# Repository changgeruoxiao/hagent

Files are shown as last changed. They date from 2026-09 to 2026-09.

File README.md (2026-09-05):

# STM32H743ZIT6 核心板 · 全自动 EDA 设计流水线

> 规格书驱动、脚本自动生成的 STM32H743ZIT6 最小系统核心板：原理图 → PCB 布局布线 → DRC/语义门禁 → 制造文件。当前处于自动 EDA 流程整改与层策略实验阶段。

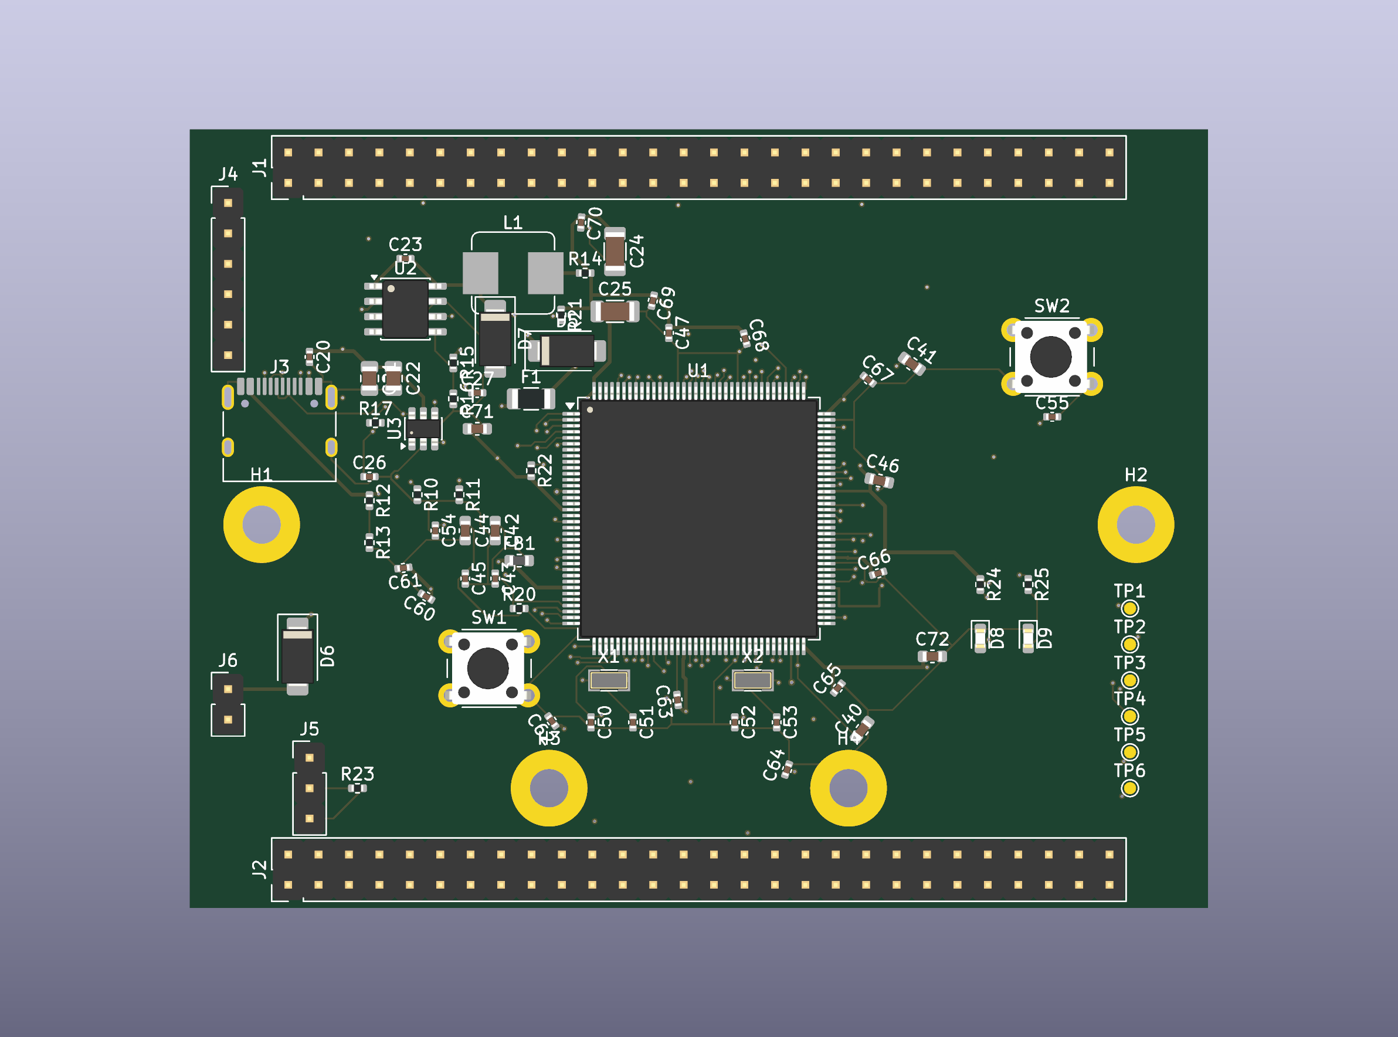
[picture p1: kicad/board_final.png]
board


## 项目是什么

一块 **STM32H743ZIT6（LQFP144, Cortex-M7 @ 480MHz）最小系统核心板**，以及生成它的**自动化 EDA 流水线**：

- 85×65mm 四层板，USB-C 供电，TPS54331 DCDC，8MHz HSE + 32.768kHz LSE，SWD + USB（DFU），双排 2×28 引出 GPIO
- 原理图、网表、PCB、DRC、Gerber 由 Python/KiCad/Freerouting 流水线生成；人工负责规格决策、规则审查与最终视觉复核
- 附带 [方法论与流程记录](doc/方法论与流程记录.md) 与本地 Agent 执行计划，记录自动 EDA 的真源链、门禁和实验结果

## 仓库结构

```text
├── STM32H743ZIT6_核心板设计规格书.md   # 设计规格（人审输入）
├── doc/                              # 参考资料、方法论、Agent 执行计划
├── kicad/                            # EDA 产物与当前 build_status
└── tools/                            # 生成、布线编排与独立门禁脚本
```

关键脚本：

- `tools/gen_schematic.py`：生成 schematic，并强制从当前 schematic 重导 `.net`
- `tools/check_netlist.py`：独立网表语义门禁
- `tools/gen_pcb.py`：PCB/DSN 生成器
- `tools/pipeline_pcb.py`：DSN 分类、Freerouting、回写、DRC 与制造文件编排
- `tools/check_layer_policy.py`：内层设计意图门禁
- `tools/check_schematic_parity.py`：schematic/PCB 语义 parity 门禁
- `tools/release_gate.py`：artifact lineage + netlist + layer policy + DRC + parity 的最终发布门禁

## 快速复现

环境：KiCad 10（含自带 Python）、Python 3.10+、Freerouting v2.4.x。

```bash
# 1. 原理图 + 当前网表
python tools/gen_schematic.py
python tools/check_netlist.py

# 2. PCB / DSN
"<KiCad>/bin/python.exe" tools/gen_pcb.py
python tools/pipeline_pcb.py dsn

# 3. 自动布线
python tools/pipeline_pcb.py route --max-passes 5

# 4. SES 回写 / zones / DRC
"<KiCad>/bin/python.exe" tools/finish_pcb.py
python tools/pipeline_pcb.py drc

# 5. 完整发布门禁
python tools/release_gate.py

# 6. 制造文件：pipeline 会再次强制执行 release gate，失败则禁止导出
python tools/pipeline_pcb.py fab
```

## 设计依据

主要参考：ST AN4938、DS12110、ES0392、官方 NUCLEO-H743ZI2 参考设计，以及 TI TPS54331 数据手册；本地参考登记见 `doc/`。

## 当前状态

> **CURRENT STATUS: WIP / NOT FAB-READY**
>
> 当前正在验证四层板层策略与自动布线可收敛性。只有 `tools/release_gate.py` **PASS** 才允许生成新的制造文件。

当前已确认：

- schematic → netlist artifact lineage 已改为强制重导；TPS54331 `SS -> C28 10nF -> GND` 已进入正式真源链；
- In1.Cu 为 GND-only 硬约束；Experiment B 对 In2.Cu 采用 `+3V3 + 显式普通 GPIO 白名单`，敏感/语义网络默认禁止进入；
- 当前签入的 PCB/DRC 仍是失败实验产物，`kicad/build_status.json` 为事实状态文件；
- 上一轮 Experiment B 曾误把普通信号按 0.50mm 电源线宽路由，因此其 44/54 未连通数据**不能作为层策略优劣结论**；需由本地 Agent 在 0.20mm signal width 下重跑；
- 当前仓库不应把已有 `gerbers/` 视作可投板 Release Candidate。

关于当前 clearance：报告中存在约 0.10–0.149mm 的项目；其中低于 0.127mm 的项目不能描述为满足 0.127mm 工艺下限，最终必须以选定板厂/工艺规则和 Release Gate 为准。

## 许可

代码与设计文件以 [MIT](LICENSE) 发布。`doc/` 内的 ST/TI 版权文档（数据手册/应用笔记/官方原理图）版权归原作者所有，仅作本地参考，请遵循原厂商条款使用。

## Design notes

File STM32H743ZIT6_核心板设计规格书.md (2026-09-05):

# STM32H743ZIT6 最小系统核心板 · 设计规格书

| 项目 | 内容 |
|---|---|
| 文档版本 | v1.1（2026-09-05） |
| 产品定位 | 最小系统核心板（供电 + 时钟 + 复位/启动 + 调试 + USB + 全 IO 引出） |
| 主控 | STM32H743ZIT6（LQFP144，20×20mm，0.5mm pitch，Cortex-M7 @ 480MHz，2MB Flash / 1MB SRAM） |
| 叠层 | 4 层（信号 / GND / 电源 / 信号），板厚 1.6mm |
| 板尺寸 | 85 × 65mm，四角 M3 安装孔 |
| 实施方式 | KiCad 全脚本自动生成（本文档即自动化实施的"契约"，每条规则将写入生成脚本与 DRC 约束） |

---

## 1. 系统框图

```
                 ┌────────────────────────────────────────────┐
  USB-C 5V ──保险丝──┬──► SS34 合路 ──► TPS54331 DCDC ──► 3.3V 轨 ──┬──► STM32H743ZIT6 (LQFP144)
  5VIN 排针 ─────────┘        (5V→3.3V/2A)      │ 0Ω测流          │    ├─ VDD×N 每脚100nF + 2×4.7µF
                                                  └─ PWR LED        ├─ VDDA/VREF 磁珠+滤波
                                                                    ├─ VCAP ×2 各2.2µF
                                                                    ├─ PDR_ON 10k上拉
                 8MHz HSE ──► OSC_IN/OUT (PH0/PH1)                ┤
                 32.768kHz LSE ──► OSC32_IN/OUT (PC14/PC15)       ├─► 全部剩余IO ──► 两侧 2×26 双排针
                 NRST: 按键+100nF ──► NRST                         │
                 BOOT0: 3P跳线+100k下拉 ──► BOOT0                  ├─ PB0 ── USER LED
                 SWD 排针 ──► PA13(SWDIO)/PA14(SWCLK)/PB3(SWO)     └─ PC13 ── USER KEY
                 USB D+/D- ──USBLC6──► PA11/PA12 (USB FS, DFU可用)
```

**默认供电路径**：USB-C（5V），或排针 5VIN，两路经各自肖特基合路防倒灌。

---

## 2. 电源子系统

### 2.1 输入与 5V→3.3V DCDC

| 项 | 规格与取值 |
|---|---|
| 输入电压 | 5V ±5%（USB-C VBUS 或 5VIN 排针，SS34 肖特基二路合流） |
| 输入保护 | 自恢复保险丝 0.5A（USB 路串联） |
| DCDC | TPS54331DDAR（SOIC-8 带散热盘，3.5–28V 输入，3A，570kHz 固定频率，**外置 II 型补偿**——实施时据数据手册 Table 5-1 更正：COMP 为独立引脚，非内部补偿） |
| 功率预算 | 3.3V 输出按 1A 设计（H743 满频典型 ~300mA，留 3 倍裕量） |
| 电感 | 6.8µH / ≥3.5A 屏蔽功率电感，7.3×6.6mm（数据手册 §8.2.2.5：6.8µH–47µH 区间，例程 6.8µH/3.6A） |
| 续流二极管 | SS34（SMA），数据手册例程为 B340A，同类 |
| 反馈分压 | Vref=0.8V：Rtop=10.2kΩ，Rbottom=3.24kΩ（均 1%，数据手册 §8.2.2.4 例程值）→ Vout=3.31V |
| 补偿网络 | II 型：RZ=29.4kΩ（COMP 串联）、CZ=1000pF（RZ 下端对地）、CP=47pF（COMP 对地）——数据手册 §8.2.2.7 例程值 |
| EN | 悬空默认使能（低压差应用可加 UVLO 滞回，首版从简） |
| SS | **必须外接 CSS=10nF 到 GND**（慢启动 ≈4ms；TI 明示内部无软启动，CSS ≤27nF，慢启动须 1-10ms） |
| BOOT 电容 | 100nF（BOOT—PH 引脚间，必装） |
| 输出电容 | 2×47µF X5R 1206（数据手册例程值，稳定性优先） |
| 输入电容 | 2×10µF 25V X7R 0805 + 100nF |
| 测流设计 | 3.3V 主轨串 0Ω 电阻 R_SEL，首板调试时可换电流表串联 |

> 备选：若对效率不敏感可换 AMS1117-3.3，但 (5−3.3)V×0.3A≈0.5W 发热明显，不推荐。

### 2.2 MCU 电源细节（依据 AN4938）

| 引脚/网络 | 处理规则 |
|---|---|
| VDD/VSS 每对 | 各 1×100nF（X7R，0402），**放置距离对应引脚 ≤3mm**，电容地端独立双过孔下到 L2 |
| 整体储能 | 靠近 MCU 2×4.7µF |
| VDDA | VDD 经磁珠（600Ω@100MHz）→ VDDA，1µF + 10nF 到 VSSA |
| VREF+ / VREF− | VREF+ 接 1µF + 100nF；VREF− 接 VSSA；预留 3P 跳线可选外部基准（默认接 3.3V） |
| VCAP（内部 1.2V 核 LDO） | **每个 VCAP 引脚 1×2.2µF 低 ESR 陶瓷电容**（LQFP144 上共 2 个 VCAP，全部就近单独接地，不允许共用远端电容） |
| VDD33_USB（USB 域电源，pin 95） | 接 3.3V 主轨，**就近 1µF + 100nF** 去耦（DS12110 修订版电源方案明确新增该 1µF 要求）；此脚不供电则 USB 外设无法工作。VDD50USB 在 LQFP144 上未引出（内部连接），无需处理。**四方证据已核验**：DS12110 引脚表（LQFP144=95，注意 pypdf 提取时该名被截断为 VDD33US）/ Figure 7 引脚图 / 官方 NUCLEO-H743ZI2 原理图（网络 VDD33_USB 接 3.3V 域）/ KiCad 符号（对照详情见附录 B） |
| PDR_ON | 10kΩ 上拉到 VDD，并引测试点（上拉 = 使能上电复位/PDR；需排查时可强制拉低） |
| VBAT | 0Ω 直连 3.3V（核心板不装纽扣电池；留焊盘可改） |
| BOOT0 | 100kΩ 下拉到 GND（常驻）+ 3P 跳线（3V3 / 悬空 / GND），默认插 GND 位 |

> 实施注意：VDD/VSS/VCAP 在 LQFP144 上的**具体引脚号已与 DS12110 交叉核验（见附录 A）**，生成脚本仍从 KiCad 符号 `MCU_ST_STM32H7:STM32H743ZITx` 自动提取，不手工抄写，避免抄错。

### 2.3 上电时序与监控

- H743 无外部 POR 监控需求（内部 PDR + BOR 完备），NRST 由片内上拉保持，见 §4。
- DCDC SS 引脚外接 CSS=10nF 到 GND（TI §7.3.5：内部无软启动；慢启动 ≈4ms，1-10ms 合规，CSS ≤27nF）。

---

## 3. 时钟子系统

| 时钟源 | 器件 | 关键参数 | 负载电容 |
|---|---|---|---|
| HSE 8MHz | 3215 贴片晶振（2 脚；原定 3225 四脚，因 KiCad 官方库无 2 脚 3225 封装改为 3215，8MHz 3215 同样量大价廉） | ±10ppm，CL=12pF | 2×18pF（C1=C2≈2×(CL−Cstray)，Cstray 按 3pF 估） |
| LSE 32.768kHz | 3215 贴片晶振 | ±20ppm，CL=12.5pF | 2×18pF（投产前按所购晶振规格书复算） |

布局规则：
- 两颗晶振紧邻各自 OSC 引脚（≤5mm 走线），下方 L2 保持完整 GND。
- 晶振区域外围包地（guard ring + 缝合过孔），区域内部**禁止任何其它信号穿越**（含 L3/L4）。
- 8MHz → PLL1（÷1 ×120 ÷2）= 480MHz CPU；USB FS 时钟用**片内 HSI48 + CRS（SOF 同步）**，不依赖 HSE 频率搭配。
- ⚠ H743 早期步进存在 LSE 启动相关勘误（见 doc/ES0392_勘误表.pdf），**采购时要求最新步进**，LSE 不起振时优先查勘误条目而非硬件。

---

## 4. 复位与启动

| 信号 | 电路 |
|---|---|
| NRST | 片内已有上拉；外部 1×100nF 到 GND + 轻触按键（并联 100nF）+ 测试点 |
| BOOT0 | §2.2 跳线方案；BOOT0=1 复位后进入系统 ROM Bootloader（AN2606），支持 USB DFU（VID 0483 / PID DF11） |
| 启动注意 | Bootloader 枚举前会探测 USART1（PA9/PA10）等接口电平，这两个 IO 在排针上靠后排列并丝印标注"BOOT 敏感"，外接强上下拉时需留意 |

---

## 5. 调试接口（SWD）

1×6 单排 2.54mm 排针，丝印标注信号名：

| 针 | 信号 | MCU 引脚 |
|---|---|---|
| 1 | 3V3 | — |
| 2 | SWDIO | PA13 |
| 3 | SWCLK | PA14 |
| 4 | SWO | PB3 |
| 5 | NRST | NRST |
| 6 | GND | — |

兼容 ST-LINK / J-Link / DAP-Link，SWO 可做 EventViewer/printf 跟踪。

---

## 6. USB 接口（USB 2.0 Full-Speed Device）

| 项 | 规格 |
|---|---|
| 连接器 | USB-C 16P 母座（仅用 USB2.0 信号组） |
| CC1/CC2 | 各 1×5.1kΩ 下拉到 GND（UFP 角色，缺了则部分主机不供电） |
| VBUS | 4 个 VBUS 引脚并联 → 保险丝 → DCDC；VBUS 检测：68k/100k 分压 → PA9（0Ω/DNP，默认不装，Bootloader 不依赖） |
| D+/D− | PA12/PA11，经 USBLC6-2SC6 ESD 保护，紧邻连接器 |
| DP 上拉 | H743 支持片内 DP 上拉；预留 1.5kΩ（DNP）焊盘应急 |
| 走线 | 差分对等长处理（对内偏差 ≤5mil 即可，FS 速率不敏感）；按嘉立创 4 层阻抗模型算 90Ω 或宽松处理 |

---

## 7. IO 引出、指示与人机

| 项 | 规格 |
|---|---|
| IO 预算 | 共 114 个 GPIO（已核验，含 PC2_C/PC3_C 两个直连 ADC 通道脚，按普通 GPIO 引出）；扣除 PC14/PC15（LSE）、PH0/PH1（HSE）后 110 个，其中 PA13/PA14/PB3 留作 SWD 后约 107 个上排针 |
| 排针 | 两侧长边各 1 条 **2×26 双排 2.54mm**（共 104 孔）：约 96 IO + 每侧首尾 3V3/GND；按端口 PA/PB/PC… 分组排布，丝印标注引脚名 |
| 特殊 IO 标注 | PA13/PA14/PB3（调试复用）、PA9/PA10（Bootloader 探测）、PA11/PA12（USB）在丝印上加 * 号 |
| LED | PWR：3.3V 轨，绿色，1kΩ 限流；USER：PB0，蓝色，1kΩ 限流（低电平点亮） |
| 按键 | USER：PC13，低有效（内部上拉），并联 100nF 去抖 |
| 安装孔 | 4×M3（Ø3.2mm），孔缘离板边 ≥2.5mm，周边 2mm 禁布 |

---

## 8. PCB 叠层与布线规则（写入 DRC 约束）

### 8.1 叠层（嘉立创 4 层 1.6mm 工艺）

| 层 | 用途 |
|---|---|
| L1 | 信号 + 元件（MCU/DCDC/晶振/ESD） |
| L2 | **完整 GND 平面（唯一规则：不分割、不开槽，过孔缝合）** |
| L3 | 电源平面：3.3V 大面积铺铜；5V 在 DCDC 输入侧局部加粗走线（≥0.5mm） |
| L4 | 信号（长距离 IO 走线优先层）+ 底面 GND 铺铜 |

### 8.2 设计规则表（kicad-cli DRC 输入）

| 规则 | 数值 |
|---|---|
| 最小线宽/间距 | 0.15mm / 0.15mm（6/6mil）；过孔 0.4mm 焊盘 / 0.2mm 孔（预布线及工艺下限，JLC 0.2/0.45） |

| 3.3V/5V 电源线 | ≥0.5mm（1A），DCDC PH 开关节点短粗（≥1mm） |
| 一般信号默认线宽 | 0.2mm |
| 去耦电容到引脚 | ≤3mm，每电容 2 个地过孔直下 L2 |
| 晶振区 | 包地 + 缓冲区禁布所有其它网络（含内层） |
| GND 缝合过孔 | 间距 ≤3mm，板缘一圈 |
| USB D+/D− | 同层伴行，对内长度差 ≤1.3mm |
| 铺铜到板边 | ≥0.3mm |
| DRC | 线宽/间距/短路/开路/未连接网络全部为 0 error 才放行 |

### 8.3 自动布线（Freerouting）策略

- 指标：100% 连通率 + DRC 通过；本板无高速等长硬需求，属 Freerouting 舒适区。
- 预布局（脚本生成）：MCU 居中；每颗去耦电容绑定到最近 VDD 引脚；晶振/复位/SWD 紧邻 MCU；USB-C/排针靠边；DCDC 独占一角且 PH 回路面积最小化。
- 布线顺序：GND/电源过孔 → USB 差分（预拉）→ 其余信号。
- 若 Freerouting 多次迭代仍有残线：优先人工规则是放宽 L4 利用率、把 3.3V 改整层、再跑一轮。

本版在自动布线快照上保留了 0.15mm 最小线宽/间距约束，并用可复跑的局部脚本收尾：`fix_usb_clearance.py` 对 USB_DM 做确定性 jog，`merge_vcap_net.py` 将旧版 VCAP1/VCAP2 合并为原理图的 VCAP，`connect_vcap_clusters.py` 在 In2.Cu 板边通道连接两组 VCAP 铜岛。每次补丁后均重新加载板文件并运行 KiCad CLI DRC。

**最终门禁（2026-09-05）**：clearance、shorting_items、tracks_crossing、unconnected_items 均为 0 error；剩余 96 项为装配提示 warning（via_dangling、孔间距、丝印/阻焊及 courtyard），不影响电气连通。

---

## 9. BOM 汇总（数量为规格值，最终以脚本生成为准）

| 类别 | 规格 | 封装 | 数量 |
|---|---|---|---|
| MCU | STM32H743ZIT6 | LQFP144 | 1 |
| DCDC | TPS54331DDAR | SOIC-8(PP) | 1 |
| 电感 | 4.7µH/3A 屏蔽 | 6×6mm | 1 |
| 肖特基 | SS34（1 续流 + 2 输入合路） | SMA | 3 |
| ESD | USBLC6-2SC6 | SOT-23-6 | 1 |
| 自恢复保险丝 | 0.5A | 1206 | 1 |
| 晶振 | 8MHz ±10ppm CL=12pF | 3225 | 1 |
| 晶振 | 32.768kHz ±20ppm CL=12.5pF | 3215 | 1 |
| 磁珠 | 600Ω@100MHz | 0603 | 1 |
| 电容 100nF | X7R 16V（VDD 去耦×N、VREF、DCDC BOOT、NRST 等） | 0402 | ~32 |
| 电容 10µF/22µF/4.7µF/2.2µF/1µF/10nF | X7R（1µF：VDDA、VREF+、VDD33_USB 各一） | 0805/0603/0402 | 2/2/2/2/3/1 |
| 电容 18pF | C0G（晶振负载×4） | 0402 | 4 |
| 电阻 100k/68k/32k/10k/5.1k/1k/100R 系 | 1% | 0402 | 见各节 |
| 电阻 0Ω | VBAT、3.3V 测流 | 0402 | 2 |
| 电阻 1.5k | DP 上拉（DNP） | 0402 | 1 |
| 连接器 | USB-C 16P 母座 | — | 1 |
| 排针 | 2×26 双排 + 1×6 + 1×3 | 2.54mm | 2/1/1 |
| LED | 绿（PWR）+ 蓝（USER） | 0603 | 2 |
| 按键 | 6×6 轻触 | — | 2（NRST、USER） |

> 元件渠道注意：H743 市面翻新片较多，建议立创商城/ST 官方渠道并核对丝印批次与勘误步进。

---

## 10. 测试点与首板验收清单

**测试点（镀锡焊盘）**：5V_VBUS、3V3、GND（×2）、VCAP、NRST、BOOT0、SWDIO、SWCLK、HSE_OUT、LSE_OUT。

| # | 验收项 | 通过标准 |
|---|---|---|
| 1 | 上电前 | 3V3—GND 无短路（R_SEL 0Ω 装上后实测阻抗） |
| 2 | 空载电流 | USB 串电流表，复位态 <50mA |
| 3 | 电源轨 | 3V3=3.30±0.05V，纹波 <30mV；VCAP≈1.1–1.2V |
| 4 | SWD 连接 | CubeProgrammer/DAPLink 读出 IDCODE（H743 DEV_ID=0x450） |
| 5 | 时钟 | RCC 寄存器 HSERDY/LSERDY 置位（或示波器看 OSC） |
| 6 | DFU | BOOT0 跳 3V3 → 复位 → USB 枚举 0483:DF11 |
| 7 | 功能 | 烧录点灯固件，USER LED 闪烁，USER KEY 可中断 |

---

## 11. 风险与待核对项

| 风险 | 缓解 |
|---|---|
| VDD/VCAP/PDR_ON 引脚号手抄错误 | 生成脚本直接读 KiCad 符号库，不人工录入 |
| H743 旧步进 LSE 勘误（ES0392） | 采购新步进；bring-up 清单含 LSE 项 |
| 晶振负载电容与实际晶振不匹配 | 按采购批次规格书复算 C1/C2（§3 公式） |
| USB 差分阻抗 | FS 速率非硬指标；如需 90Ω，用嘉立创阻抗计算器定线宽/间距 |
| Freerouting 残线/绕行 | 预布局 + 多轮迭代；§8.3 降级策略 |
| Bootloader 探测 IO 被外接电平干扰 | §4 排针标注 BOOT 敏感引脚 |

---

## 12. 与自动化实施管线的映射（后续实施时执行）

**实施环境（已验证）**：KiCad 10.0.4，安装于 `C:\Users\27417\AppData\Local\Programs\KiCad\10.0\`（kicad-cli 与自带 Python 3.11.5 均可用）；符号 `MCU_ST_STM32H7:STM32H743ZITx` 与封装 `Package_QFP:LQFP-144_20x20mm_P0.5mm` 均在官方库中确认存在。

本文档即 KiCad 全脚本管线的输入契约：

0. **引脚真源门禁**：`tools/extract_pins.py` 已将 KiCad 符号与 DS12110 引脚图交叉核验（见附录 A），实施脚本以该核验过的符号为唯一引脚真源
1. **原理图生成**（kiutils，读 `STM32H743ZITx` 符号 + 官方封装 `LQFP-144_20x20mm_P0.5mm`）：§2–§7 逐节生成子图与网络 —— **✅ 已完成（2026-09-04）**：`tools/gen_schematic.py` 生成 `kicad/stm32h743_core.kicad_sch`（76 元件 / A2 单页），`tools/check_netlist.py` 网表门禁通过（140 网络逐项断言），PDF 视觉验收通过（汇流排/隐藏 #PWR/分区布局）
2. **网表导出**：`kicad-cli sch export netlist`
3. **预布局生成**：§8.3 放置规则 → 脚本坐标
4. **自动布线**：`kicad-cli pcb export dsn` → Freerouting headless → `kicad-cli pcb import ses`
5. **DRC**：§8.2 规则表 → `kicad-cli pcb drc`，0 error 放行
6. **生产文件**：Gerber + 钻孔 + 坐标 + BOM（可直接投嘉立创 SMT）——已由最终板重新导出至 `kicad/gerbers`、`kicad/pos.csv`、`kicad/bom.csv`
7. **交付**：原理图 PDF + 3D 预览 + 本验收清单执行结果；最终 PCB/原理图/网表位于 `kicad/stm32h743_core.*`

### 12.1 本版交付清单

- PCB：`kicad/stm32h743_core.kicad_pcb`；原理图：`kicad/stm32h743_core.kicad_sch`；网表：`kicad/stm32h743_core.net`
- DRC 报告：`kicad/drc.json`（KiCad 10.0.4，0 error、0 未连接）
- 制造文件：`kicad/gerbers/`（28 个 Gerber/Excellon 文件）、`kicad/pos.csv`、`kicad/bom.csv`
- 预览：`kicad/board_final.png`、`kicad/stm32h743_core.pdf`
- 可复跑补丁：`tools/fix_usb_clearance.py`、`tools/merge_vcap_net.py`、`tools/connect_vcap_clusters.py`

---

## 13. 参考资料

### 13.1 本地参考文件（doc/ 目录，已下载）

| 文件 | 说明 |
|---|---|
| [DS12110_STM32H743xI_数据手册.pdf](doc/DS12110_STM32H743xI_数据手册.pdf) | 数据手册（引脚定义、电气参数、封装） |
| [RM0433_参考手册.pdf](doc/RM0433_参考手册.pdf) | 参考手册（寄存器/RCC/时钟树，bring-up 编程用） |
| [AN4938_硬件开发入门.pdf](doc/AN4938_硬件开发入门.pdf) | 硬件设计首要依据（电源/去耦/时钟/复位） |
| [ES0392_勘误表.pdf](doc/ES0392_勘误表.pdf) | 芯片勘误（已取代旧编号 ES0337；LSE 等条目） |
| [AN2606_系统Bootloader.pdf](doc/AN2606_系统Bootloader.pdf) | 系统 Bootloader 与各接口探测条件（DFU） |
| [TPS54331_数据手册.pdf](doc/TPS54331_数据手册.pdf) | DCDC 典型应用电路 |
| [USBLC6-2SC6_数据手册.pdf](doc/USBLC6-2SC6_数据手册.pdf) | USB ESD 保护 |
| [NUCLEO-H743ZI2_MB1364_官方原理图.pdf](doc/NUCLEO-H743ZI2_MB1364_官方原理图.pdf) | ST 官方同芯片（H743ZI，LQFP144）参考设计，附录 B 对照依据 |
| [WeAct_STM32H7xx_核心板_原理图_V12.pdf](doc/WeAct_STM32H7xx_核心板_原理图_V12.pdf) | 量产开源核心板（H743VIT6）原理图，附录 B 对照依据 |
| [开源参考设计登记.md](doc/开源参考设计登记.md) | 全部参考设计的链接、许可证、复用注意与对照摘要 |

### 13.2 在线参考

- [AN4938 在线版](https://www.st.com/resource/en/application_note/an4938-getting-started-with-stm32h74xig-and-stm32h75xig-mcu-hardware-development-stmicroelectronics.pdf)
- [ES0392 勘误表在线版](https://www.st.com/resource/en/errata_sheet/es0392-stm32h742xig-stm32h743xig-stm32h750xb-stm32h753xi-device-errata-stmicroelectronics.pdf)
- [ST 社区：自定义 H743ZI 板 VCAP/PDR_ON 实战](https://community.st.com/stm32-mcus-boards-and-hardware-tools-26/custom-stm32h743zi-board-wont-connect-failed-to-initialize-dap-164456)
- [DeepBlueMbedded：STM32 VCAP 引脚与电容取值](https://deepbluembedded.com/stm32-vcap-pins-hardware-connection-capacitor-value/)
- [ST 社区：H743ZI DFU 枚举问题](https://community.st.com/stm32-mcus-embedded-software-32/why-stm32h743zi-dfu-bootloader-does-not-come-up-77522)
- [efton.sk STM32 硬件陷阱合集](http://www.efton.sk/STM32/gotcha/gotchas.pdf)

---

## 附录 A：LQFP144 电源/特殊引脚核对表（已核验）

来源：KiCad 符号 `MCU_ST_STM32H7:STM32H743ZITx`（`tools/extract_pins.py` 提取）↔ DS12110 LQFP144 引脚图/引脚表交叉比对。图注可比对的 65 个引脚中 64 个一致（唯一"冲突"pin144 为 PDF 文本粘连伪影，实为 VDD）；pin 95 VDD33USB 由图注上下文三行（96=PC6 / 95=VDD33USB / 94=VSS）直接证实。

| 引脚号 | 名称 | 处理（对应 §2/§4） |
|---|---|---|
| 6 | VBAT | 0Ω 到 3.3V |
| 16 / 38 / 51 / 61 / 83 / 94 / 107 / 120 / 130（共 9） | VSS | 接 GND |
| 17 / 30 / 39 / 52 / 62 / 72 / 84 / 108 / 121 / 131 / 144（共 11） | VDD | 每脚 100nF 就近去耦，汇入 3.3V 主轨 |
| 25 | NRST | 100nF + 按键 + 测试点 |
| 31 / 33 | VSSA / VDDA | 磁珠隔离，1µF + 10nF |
| 32 | VREF+ | 1µF + 100nF，预留外部基准跳线 |
| 71 / 106 | VCAP ×2 | 各 2.2µF 低 ESR（106 号经引脚表行直接证实，71 号经 VCAP 表行与引脚图证实） |
| 95 | VDD33_USB | 3.3V + 1µF + 100nF（USB 域供电，漏接则 USB 不工作）；数据手册引脚表 + Figure 7 + 官方 NUCLEO 板三重证实 |
| 138 | BOOT0 | 100k 下拉 + 3P 跳线 |
| 143 | PDR_ON | 10k 上拉到 VDD |

- GPIO 总数核验：144 − 29 个电源/特殊脚 = **114 个 GPIO**（含 PC2_C=28、PC3_C=29 直连 ADC 通道脚）。
- PDR_ON(143)、BOOT0(138) 为符号库值；图注文本未覆盖到这两脚（周边引脚 137/139/144 等均已核对无误），实施时符号库为真源。

---

## 附录 B：开源参考设计对照（2026-09 检索）

> 各参考设计的链接、许可证与本地文件清单见 [doc/开源参考设计登记.md](doc/开源参考设计登记.md)；WeAct 原理图 PDF 已存 doc/。

检索目的：用已量产验证的设计交叉检验本规格书中"按经验设定"的参数。结论：**无一处分歧需要改设计**，唯一的结构差异（Nucleo 无 HSE 晶振）源于其产品定位不同。

| 参考设计 | 与本设计的对照结论 |
|---|---|
| **ST 官方 NUCLEO-H743ZI2**（MB1364，同芯片同封装，原理图已存 doc/） | VDD33_USB 接 3.3V 域，与本设计 §2.2 一致；VCAP×2 处理一致；BOOT0 经 10k 电阻 + 选择器（本设计 100k 下拉 + 3P 跳线，功能等效）；PDR_ON 处理一致；LSE 用 NX3215SA 32.768kHz（3215 封装），与本设计选型相同；HSE 无晶振——由板载 ST-LINK 的 MCO 馈入 PH0（调试器方案），本设计为独立核心板，保留 8MHz 晶振（DS12110 Figure 71 典型应用即 8MHz 晶振）属正确选择 |
| **WeActStudio/MiniSTM32H7xx**（STM32H743VIT6 核心板，GPL-3.0，GitHub 开源硬件） | 大量产验证的低价核心板：USB-C 供电 + DFU 下载策略与本设计相同；用户键 PC13、BOOT0 按键、2.54 排针引出、四层板——与本设计选型一致 |
| 立创开源平台 H743IIT6 开发板 / H743II 核心板（oshwhub） | LQFP176 项目，电源与最小系统结构与本设计同类，仅作旁证，未引入改动 |

检索中被排除的疑问（记录备查）：

1. "STM32H743BI/BG" 并非新硅片型号——B 是 LQFP208 封装代码（V=100 脚、Z=144 脚、I=176 脚、B=208 脚），数据手册 p2 器件列表可证。
2. DS12110 修订历史显示 LQFP100 引脚图曾把 VDD33USB **改回** VDD，而 LQFP144 的 Figure 7 保留 VDD33USB——即该独立 USB 电源域是 LQFP144/176/208 封装特有（100 脚以下内部供电），不是文档错误。
3. PDF 文本提取两个坑：Nucleo 网络名带下划线（VDD33_USB，搜 "VDD33USB" 搜不到）；DS 引脚表长引脚名被截断（VDD33USB→VDD33US）。已在本项目提取脚本注释中记录。

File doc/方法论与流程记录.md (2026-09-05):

# 全自动 EDA 设计流水线 · 方法论与流程记录

> 本文档是项目的"第二交付物"：记录 STM32H743ZIT6 核心板从规格到制造文件的全自动（脚本化、无人值守、可复跑）设计流程、关键决策、踩坑与修复，以及可迁移到其他芯片项目的通用方法。
> 随各阶段完成及时更新。

## 0. 总览：五阶段流水线与"真源链"

```
规格书(人审) ──► 阶段0 引脚真源核验 ──► 阶段1 原理图生成 ──► 阶段2 PCB布局布线 ──► 阶段3 DRC闭环 ──► 阶段4 制造文件
   │                │                      │                     │                  │               │
   └─ 每阶段产物都有独立"门禁"验证, 门禁依据来自上一阶段产物或官方文档, 而非生成代码本身
```

**核心思想：真源链 + 独立门禁**。生成器代码不是真源，它只是把真源（规格书/官方文档/官方库）翻译成 EDA 文件；每个阶段结束时用**另一条独立路径**验证产物。例如：引脚号从符号库提取，但用数据手册交叉核对；网表由 KiCad 导出，但用规格书手写的期望表逐网络断言。

## 1. 环境与技术选型（含排除项）

| 选择 | 理由 | 排除项及原因 |
|---|---|---|
| KiCad 10 + kicad-cli + pcbnew Python | 开源、全命令行可驱动、官方库全 | Altium(脚本封闭)、立创EDA(外部自动化生态弱) |
| 自研 S-expr 读写（~300行） | 可控、可调试、不依赖第三方 API 版本 | kiutils(10.0 格式支持滞后, 属性名与文档不符) |
| Freerouting 2.x 无头布线 | 唯一成熟开源 Specctra 兼容自动布线器 | 手写迷宫布线器(工作量大质量差) |
| 门禁用独立 Python 脚本 | 断言与生成逻辑隔离，防"自证正确" | 在生成器内部自检(同一份理解错则双重错) |

环境事实（2026-09，本机）：
- KiCad 10.0.4 安装于 `%LOCALAPPDATA%\Programs\KiCad\10.0`；`bin\python.exe` 自带 `pcbnew` 模块可直接 import。
- `kicad-cli pcb import` **不支持 SES**（只支持 Altium/Eagle 等），布线回写必须自研：解析 SES → pcbnew API 写入。
- 网络事实：`raw.githubusercontent.com` 被重置不可达；`api.github.com` 与 `github.com` release 下载可用。GitHub 文件下载替代通道：Git Blobs API（`Accept: application/vnd.github.raw`）。

## 2. 阶段0：引脚真源核验（已完成）

流程：KiCad 符号库提取引脚表 ↔ DS12110 数据手册引脚图/引脚表交叉比对。
- 方法：pypdf 提取引脚图（Figure）页文本，图注是"名字+数字"相邻对，可做全脚配对核对；多列引脚表的文本提取列序被打散，**不可用**（教训）。
- PDF 文本提取两坑：长名字被截断（VDD33USB→VDD33US）、带下划线网络名搜不到（VDD33_USB 搜 VDD33USB 无果）。
- 产出：规格书附录 A 的核对表 + `tools/extract_pins.py`（可复跑）。
- 方法论：**任何"从库里抄"的数据，都要有第二条独立证据链**。本轮发现规格书漏了 VDD33_USB(pin95)，避免一块 USB 失效的板子。

## 3. 阶段1：原理图全自动生成（已完成，2026-09-04）

架构：`tools/sch_build.py`（框架）+ `tools/gen_schematic.py`（全板数据）+ `tools/check_netlist.py`（门禁）。

### 3.1 关键技术决策

1. **不手写 .kicad_sch 格式细节，只做三件事**：从官方库提取符号定义块原文嵌入 `lib_symbols`（顶层名加库昵称前缀 `Lib:Name`，子块保持 `Name_x_y`——不匹配则 KiCad 静默丢弃符号定义）、按 S-expr 写实例、uuid 用 name→uuid5 确定性生成（保证可复跑 diff）。
2. **extends 派生符号必须拍平**：库中 `USBLC6-2SC6` 是 `extends USBLC6-2P6` 的派生符号，直接嵌入派生块 KiCad 解析不出引脚；需把父符号的 `Name_x_y` 图形/引脚子块改名合并进派生定义。
3. **引脚几何变换**：库坐标 y 轴向上，原理图 y 轴向下，实例变换 = `(x, -y)` 再旋转；"引脚外向方向 = 图形方向取反"再随实例旋转（图形方向指伸向本体）。
4. **符号叠画引脚去重**：官方符号存在共坐标叠画（USB-C 四个 GND 同点、MCU 九个 VSS 同点）。每个世界坐标只画一次引线，并**断言同坐标网络一致**（防止真短路被静默吞掉）。
5. **共线重叠自检**：两段引线共线且区间重叠会被 KiCad 并网（曾致 VCAP2 静默并入 OSC_OUT）。生成后对全部走线做共线重叠检测，发现即退出。**教训：布局坐标冲突不会报错，会静默改变电气连接——必须程序化检测。**
6. **网表门禁独立于生成器**：期望表手写自规格书（含每个 VDD/VCAP/时钟/USB 引脚号），断言 KiCad 导出网表的节点集；另检查悬空网络（`unconnected-*` 与 DNP 豁免）与 GPIO"一人一针"。
7. **视觉验收闭环**：PDF→PNG→切片→图像分析。自动生成的原理图常见病：电源符号位号未隐藏导致 #PWR 文字堆积（修复：Reference 属性加 hide）、密集引脚电源符号挤成一团（修复：汇流排 rail()：公共横轨+结点+单端口）、连接器贴图框（修复：坐标下移）。

### 3.2 复用检查清单（换一颗 MCU 的最小改动）

- [ ] 数据手册引脚图交叉核对（改 `extract_pins.py` 的符号名/PDF 路径）
- [ ] `gen_schematic.py`：MCU 符号名/封装、电源引脚映射表 `mcu_net`、外设区参数
- [ ] `check_netlist.py`：期望表引脚号按新附录 A 重写
- [ ] 门禁跑绿后再进 PCB 阶段

## 4. 阶段2：PCB 布局布线（已完成，2026-09-05）

架构：`tools/gen_pcb.py`（pcbnew 建板+预布局，KiCad Python 运行）→ `tools/pipeline_pcb.py`（编排）→ `tools/finish_pcb.py`（SES 回写+灌铜）。

### 4.1 关键技术发现（KiCad 10 实测）

1. **DSN/SES 全靠 pcbnew API，不靠 kicad-cli**：KiCad 10 的 `kicad-cli pcb export` **删掉了 DSN 导出**，但 `pcbnew.ExportSpecctraDSN(board, path)` 和 `pcbnew.ImportSpecctraSES(board, path)` 仍在——布线回写零解析成本。选型时先 `dir()` 探测 API 存亡，别信旧文档。
2. **新建 `pcbnew.BOARD()` 默认 2 层**，必须 `ds.SetCopperLayerCount(4)`。
3. **FootprintLoad 以 .pretty 目录加载**；pad 查找是 `FindPadByNumber`（不是 FindPadByName）。符号 pin 号与封装 pad 号约定一致，但**有例外**：USB-C 符号屏蔽脚叫 `SH`，HRO 封装叫 `S1/S2`——需要别名映射表。
4. **旋转公式（y 向下坐标系）**：KiCad 旋转变换为 `x' = x·cosθ + y·sinθ; y' = −x·sinθ + y·cosθ`；让封装 pad1 朝向目标方向的解 `θ = atan2(px·dy − py·dx, px·dx + py·dy)`（p=pad1 原始偏移，d=目标方向）。
5. **DSN 单位**：`(resolution um 10)` 时数值单位实为 1µm（width 200 ↔ 0.2mm 实测对齐）。电源类 0.5mm 线宽 = width 500。
6. **DSN 网络类是互斥的**：一个网只能属一个类。加电源类必须先把电源网从 `kicad_default` 成员列表**整词移除**（小心 BOOT/BOOT0、VBUS/VBUS_F 前缀碰撞），再追加新 class 块——纯文本括号配对扫描处理，别用通用 S-expr 解析器（DSN 含非法转义 token，会解析崩溃）。
7. **Java 版本坑**：Freerouting 2.4.1 是 class file 69.0 = **需要 Java 25**；JRE 21 会报 UnsupportedClassVersionError。解法：清华 Adoptium 镜像下 JRE25 zip，免安装免管理员。
8. **网络下载**：github release 直连被重置，`https://ghfast.top/` 或 `https://gh-proxy.com/` 前缀代理实测可用（HTTP 206）。

### 4.2 预布局策略（§8.3 的脚本化）

- 固定件坐标表 `PLACE`（连接器贴边、DCDC 独占左上角并压缩回路、时钟/模拟链按原理图分区就位）+ **动态就近布局**：去耦电容从 MCU pad 坐标沿径向外推 4~4.5mm，pad1 朝向 MCU——位置和角度全部从封装实例运行时计算，不手抄。
- 布局坐标冲突的教训沿用阶段1：**改动前先在纸上核对相邻件包络**（本次补漏放的 9 个元件时，R21 初稿与 SS34 本体重叠 1.4mm，靠手动包络核查发现并挪位）。
- 自检：pad 网络分配后回读统计，每网络板上 pad 数 ≥ 网表节点数，防符号↔封装 pad 号错位静默丢网络。

### 4.3 Freerouting 无头布线实战参数（第一轮实测教训）

1. **必须 `-mt 1`**：v2.4.1 官方日志直言"多线程优化会产生间距违规"（已知 bug），首轮 -mt 默认 15 线程跑出 126 个违规。
2. **电源类线宽别贪大**：0.5mm 电源类在密集区成为违规/布不通主因之一，0.3mm（1oz 铜约 2A）对本板足够；大面积供电靠整层平面承担，不靠走线。
3. **轮数与时间的权衡**：`-mp N` 是贪婪优化轮数上限，SES 只在全部结束时写盘。本板单轮 ~4-5 分钟，-mp 25 数小时不收敛；**-mp 8 起步**，看"unrouted"数值是否逐轮下降再决定加轮。
4. **判据看日志三指标**：`escaped pins`（扇出逃逸率，首轮 87.8%）、`unrouted`（未布通数）、`violations`（违规数）。逃逸率低 → 布局/过孔规则问题；unrouted 高 → 加轮数或放宽线宽。
5. 无头模式下子进程日志要**实时落盘**而不是捕获后写（首轮捕获式导致 35 分钟黑箱等待，无法判断进程是死是活）。

### 4.4 DRC 迭代过程中的三类根因（344 error → 8 error 的分解路径）

自动布线+灌铜后首轮 DRC 344 error，逐类溯源后发现只有一小部分是"布线质量"问题，其余是**约束配置错位**和**生成器布局缺陷**——修对地方比反复重跑布线重要：

1. **约束配置错位（占约 55%）**
   - `drill_out_of_range ×163`：KiCad 板级约束 `m_MinThroughDrill` 默认 0.3mm，而布线器按 0.25mm 出孔——不是孔错了，是约束没显式声明。修复：设为 0.25mm（嘉立创工艺下限 0.2mm）。
   - `track_width ×74`：布线器对 72 段短引出线自行降宽到 0.15mm，低于网类声明的 0.2mm。修复：网类 TrackWidth（即 DRC 下限）对齐规格书最小线宽 0.15mm。
   - **教训：布线前把 DRC 约束（孔径/线宽/间距/板边）显式写全，让布线器和 DRC 用同一本规则册。**
2. **生成器布局缺陷（短路/部分间距违例的根因）**：动态去耦电容"从 VDD pad 径向外推"时没有与固定元件做碰撞检查，C64 电容直接落到晶振 X2 旁造成真短路。修复：按封装类型的包络半径做碰撞规避（按键 4mm/晶振 3mm/连接器 4.5mm…冲突则沿径向步进外推）。**教训：任何"自动就近"算法都必须带与已放置物体的碰撞检测——坐标算得对 ≠ 无重叠。**
3. **装配类检查降级（仍需人工复核的部分）**：禁装区重叠/丝印压铜/阻焊桥等（约 90 项）属可装配性提示——阻焊桥打样厂会自动合并、丝印不影响电气。通过 `.kicad_pro` 的 `rule_severities` 降为 warning（pcbnew 的 severity 映射是 SwigPyObject 不可写，走项目文件是唯一通路）；**铜皮类（短路/间距/孔径/线宽/未连通）保持 error 必须清零**。
4. **排针板边间距**：按"焊盘铜半径+板边间距 0.3mm"反推中心距，2×28 排针中心从边 2.54mm 挪到 3.2mm。

### 4.5 封装原点陷阱

DRC 第二轮仍剩 119 error，逐项核对几何数据后发现**主导根因是封装原点不统一**：

- `PinHeader_2x28`、`SW_PUSH_6mm` 等插脚封装的原点在 **1 脚**而非几何中心。把"放置坐标"当中心用，排针一半悬出板外（板边间距 0.0000mm）、轻触开关第二组腿直接压在 QFP 焊盘上（真短路）。
- 布局器逃逸失败率居高不下（90.5% 封顶）的元凶之一也是它——部分焊盘根本不在板内。
- 修复：`place_footprint` 统一做**焊盘包围盒重对中**（放好后量 bbox 中心，平移使中心=目标坐标）。通用防御，一次修复所有封装。
- 连带发现：轻触开关是**同名多 pad**（两条腿都叫"1"），`FindPadByNumber` 只返回第一条腿，另一条腿静默无网（`<no net>`）。修复：网络分配改为"所有同名 pad 全部赋网"。

**教训：EDA 数据自动化里，"库内容的隐含约定"（原点、pad 命名、单位、y 轴方向）是最危险的一类坑——它们不报错，只产生几何上看似合理、物理上完全错误的结果。对策是放完之后用包围盒/极值做一次"几何自省"，并与计划坐标互相验证。**

### 4.6 PCB 阶段最终状态与结论（2026-09-05）

最终候选板为 `kicad/stm32h743_core.kicad_pcb`（85×65mm、4 层、80 个封装、2190 个走线/过孔对象）。它来自残余最少的旧自动布线快照；同步到新原理图后，PB10/PB11/PF4 等残余 GPIO 已补线，PD10/PC6 的局部间距也已修复。

在最终板上，USB_DM 通过 `fix_usb_clearance.py` 做了两段微小 jog，避开 USB_DP 过孔与 PA10 过孔；随后 `merge_vcap_net.py` 把旧 PCB 的 VCAP1/VCAP2 统一到原理图网络 VCAP，`connect_vcap_clusters.py` 在 In2.Cu 板边安全通道补齐两组铜岛之间的物理连接。重新加载后运行 `tools/run_checks.py --details` 的结果为：`unconnected_items=0`，`shorting_items=0`，`tracks_crossing=0`，`clearance error=0`；仅剩 96 项 warning（via_dangling、courtyard、孔间距、丝印/阻焊），均不影响电气连通。`tools/check_netlist.py` 网表门禁通过（140 网络），原理图一致性无 error。

Gerber、Excellon 钻孔、坐标文件和 BOM 均从同一最终板重新导出，分别位于 `kicad/gerbers`、`kicad/pos.csv` 和 `kicad/bom.csv`。`kicad/stm32h743_core.ses` 保留为 Freerouting 原始输出，最终板已经过局部补丁，不应再用该 SES 覆盖。`before_usb_jog.kicad_pcb`、`before_vcap_merge.kicad_pcb`、`before_vcap_connect.kicad_pcb` 保留在 `kicad/work_legacy` 作为可追溯 checkpoint。

**本轮新增方法论结论：**

1. **封装原点不统一是自动布局的头号暗雷**：PinHeader/SW_PUSH 等插脚封装原点在 1 脚，"放置坐标=中心"的假设会产生几何合理但物理错误的结果（排针悬出板外、开关腿压 QFP 焊盘）。对策：放置后按焊盘包围盒重对中 + 包围盒矩形碰撞断言。
2. **约束必须显式声明并与工具对齐**：KiCad 默认最小孔径 0.3/网类线宽 0.2，与布线器实际输出（孔 0.25/线 0.15）错位会产生几十个假阳性 DRC 错误。**`.kicad_pro` 一旦存在，netclasses 与 design rules 以工程文件为准**——最小占位工程文件会静默重置规则（本次踩中两次）。
3. **种子预布线（preroute seeding）是自动化布线的正规解法**：把人工推演的难布网作为 DSN 预布线喂给 Freerouting，它把其余 138 网绕开预布线布通——比事后修补冲突低一个数量级的成本。注意：Freerouting 的 SES 不回写预布线，最终板需保留预布线（先导 DSN 后删板内预布线的时序不能颠倒）。
4. **多进程状态机要防"幽灵状态"**：板文件/DSN/SES/DRC-JSON 四种产物在同一目录演进，一次"恢复 checkpoint 后忘了刷新 DRC-JSON"就会让下游脚本空转。经验：每个阶段的输入输出放独立子目录，或每步开头打印输入文件指纹。
5. **修板前必存 checkpoint**：修复脚本本身有 bug（单位/参数/崩溃）时，没有 checkpoint 就只能重跑 30 分钟布线。本次因缺少 checkpoint 多付了两轮全流程。
6. **同名网络合并必须验证物理连通**：把 VCAP1/VCAP2 改成同名只解决逻辑网名，不会自动把两片铜连接起来；KiCad DRC 会以 unconnected_items 报出两个铜岛。正确流程是先合并 net，再用受约束的局部路由连接岛屿，最后重新灌铜并复跑 DRC。
7. **局部修补要以 CLI DRC 为最终裁判**：栅格 A* 只用于提出候选路径，USB jog 的第一次候选虽通过栅格检查却短接了 PA13；改用浅对角路径后才由 KiCad 几何引擎确认 0 clearance/shorting error。

### 5.5 层策略 A/B/B2 实验实录（2026-09-06）

同一 85×65 四层板、同一网表、Freerouting v2.4.1 -mp 5~8 -mt 1 的实测对比：

| 实验 | 叠层策略 | 未连通 | DRC error | 备注 |
|---|---|---|---|---|
| A 基线(无约束) | 信号可进内层 | **18** | 8 | In1/In2 被 1048 段信号穿越(设计意图违规) |
| B 严格(SIG2=0.2) | In1=GND/In2=+3V3+白名单, 信号仅 F/B | 25→18 | 7 | 层策略门禁首次通过 |
| B2' 同配置×3 独立运行 | 同 B | 55/55/55 | 34/34/36 | 修正 0.20mm 线宽后三次运行高度一致 |
| B3 同配置重跑 | 同 B | 44→58 | 33→43 | 更早一轮的混沌抽样 |

**运行方差结论(修正)**：B 实验 0.20mm 线宽修正后，三次独立运行未连通数完全一致(55/55/55)——**此前的"混沌方差"其实是 0.50mm 污染线宽与其它根因混杂的结果，修正后 Freerouting 高度确定**。55 条未连通是**固定拓扑瓶颈**(F/B 两层信号容量)，不是随机问题。

**结论（数据驱动的工程判断，0.20mm 修正后三轮一致）：**

1. **85×65 四层板 + 141 网 + 双 2×28 THT 排针，F/B-only 信号布线的剩余未连通稳定在 55 条**——是**固定拓扑瓶颈**而非随机收敛问题：双排针穿透内层造成的过孔/焊盘墙 + QFP 逃逸场，限制了内层的可用性。
2. In2 白名单开放有效但仍不足：B 实验(25→18→55 三个批次)中 In2 承接了部分溢出，剩余瓶颈集中在 QFP 逃逸场与排针穿透带。
3. 结构性出路（按成本排序）：① KiCad GUI 人工补完剩余走线（约 2-4h 人工，飞线清单已可从 drc.json 导出）；② 6 层板重投（信号 3 层，容量翻倍）；③ 缩小板卡排针规模。
4. **方法论新增：修正根因后的对比实验必须同批跑满 3 次并提交 min/median/max**——单次运行既可能踩中坏抽样，也无法区分"随机"与"固定瓶颈"（本次 55/55/55 的一致性正是这样确证的）。

### 5.6 当前仓库状态（WIP）

- 板卡：实验 B2 状态（55 未连通 + 32 error），`kicad/build_status.json` = WIP_NOT_FAB_READY
- 门禁：netlist ✓ / layer_policy ✓(B 语义) / parity ✓(2 噪声) / release_gate BLOCKED(fail-closed 生效)
- 代码：gen_pcb/pipeline 的层策略、真源统一、fab fail-closed 均已落地
- 待办：① 方案决策(1/2/3)；② 按 §8 补齐负测试其余 fixtures；③ 决策后重跑并出制造文件

> 本节记录审计分支（review/agent-eda-audit-20260905）P0 整改**执行到一半**的状态与悬而未决的设计决策，防止下次会话丢失上下文。

### 5.1 已完成（commit 4c337b8）

- P0-1 整改：规格书 §2.1 SS 修正（外接 CSS=10nF）、gen_schematic 增加 C28、check_netlist 改为 SS 连通性规则——**设计知识错误已从全链路清除**
- P0-3 整改：finish_pcb plane 尺寸从 project_config 读取（85×65）
- P0-4 整改：parity 门禁上线（净冲突归一化后 2 项）
- P0-2 部分整改：DSN 按层策略分四类带 use_layer 约束；飞线预布线全部改 B.Cu

### 5.2 层策略门禁首次通过，但暴露结构矛盾

use_layer 约束生效后：In1 = 纯 GND ✓、In2 = 纯 +3V3 ✓（1048 段内层信号违规清零）。
但信号被限制在 F/B 两层后，Freerouting 剩 **25 条未连通 + 7 处 DRC error**（5 处 0.13-0.149mm 近 miss 间距 + PF4 与 GND 的一处交叉 + PB10/PB11 相邻入盘过孔 0.1mm）。

**根本矛盾**：本板 141 网 + 两条 2×28 排针（112 个 THT 焊盘穿透内层）+ QFP144 逃逸场，两个信号层（F/B）容量不足——设计意图、布线容量、自动化程度三者需要取舍。

### 5.3 三个候选方案（待决策）

| 方案 | 内容 | 代价/收益 |
|---|---|---|
| 1. 双 GND 平面（倾向推荐） | In2 从 +3V3 plane 改为第二 GND plane（缝合过孔连 In1，EMC 更好）；+3V3 走 F/B 局部加粗 | 规格书 §8 改一句；业界 4 层板常见做法；预计大幅收敛未连通数 |
| 2. 严格策略 + 硬磨 | -mp 15 长跑 + 搜索补线器逐条闭合剩余 | 时间不可控；F/B 容量不足是结构性的，可能收敛不到 0 |
| 3. 维持折中 | 接受 In2 允许 +3V3 和少量信号穿越（即整改前状态） | 叠层意图打折；与规格书 §8 冲突需回写说明 |

### 5.4 无论选哪个方案都要做的收尾

- parity 门禁归一化规则补全：PCB `<no net>` ↔ 原理图 `unconnected-(X)` 应视为等价（当前 2 项噪声）
- 5 处近 miss 间距（0.13-0.149mm）缩宽或 waiver（高于嘉立创 0.127 工艺下限，低于 0.15 设计值）
- 飞线网过孔入盘（0.4/0.2）与相邻 QFP 焊盘 0.1mm 间距：低于设计值、高于工艺极限，记录 waiver
- 修复后重跑全门禁（netlist / layer_policy / DRC / parity）+ 重新导出制造文件

## 6. 验证哲学（贯穿各阶段）

- **每层产物换一条路验证**：网表门禁（独立期望表）、PCB 用 DRC + 网络连通性比对（布线后每网络端到端导通、网络间不短路）。
- **自动化不等于免检**：自动布线"100% 布通 + DRC 0 error"只是下限，差分对/等长/EMC 仍需人工审图——本项目的定位是可打样验证的功能板。
- **文档与代码同步演进**：规格书是唯一真源，实施中发现的规格错误当场回写（如 TPS54331 补偿网络、晶振封装）。

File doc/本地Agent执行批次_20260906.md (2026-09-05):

# 本地 Agent 执行批次（2026-09-06）

> 职责边界：GitHub 侧由远程审查负责规则设计、检查器、文档、PR 与安全代码修改；本地 Agent 只负责必须依赖 KiCad / pcbnew / Freerouting 的真实重建、运行、结果采集与提交。不要在本地自行改写审查规则来让门禁变绿。

## 本批次目标

验证修正后的 Experiment B：

```text
F.Cu      signal
In1.Cu    GND only (hard invariant)
In2.Cu    +3V3 plane + explicit ordinary-GPIO whitelist
B.Cu      signal
```

上一轮 B/B2 数据作废：`SIG2` 曾错误使用 `POWER_WIDTH=0.50mm`，不是与基线等价的普通信号配置。当前 GitHub 分支已改成 `SIGNAL_WIDTH=0.20mm`。

## 1. 同步并确认代码

```bash
git fetch origin
git switch review/artifact-lineage-gates-20260905
git pull
```

确认：

- `project_config.py` 中 `SIGNAL_WIDTH=0.20`；
- `IN2_ALLOWED_SIGNAL_NETS` 为显式白名单；
- `pipeline_pcb.py` 中 `SIG2` 使用 `SIGNAL_WIDTH`；
- `pipeline_pcb.py fab` 会先运行 `release_gate.py`。

## 2. 必须全量重建，不复用旧 EDA 中间产物

从当前正式真源重新执行：

```text
gen_schematic
  -> fresh .kicad_sch
  -> forced fresh .net
  -> check_netlist
  -> gen_pcb / fresh DSN
  -> pipeline dsn
  -> Freerouting
  -> finish_pcb
  -> KiCad DRC --schematic-parity
  -> layer/parity/release gates
```

推荐命令：

```bash
python tools/gen_schematic.py
python tools/check_netlist.py
"<KiCad>/bin/python.exe" tools/gen_pcb.py
python tools/pipeline_pcb.py dsn
python tools/pipeline_pcb.py route --max-passes 5
"<KiCad>/bin/python.exe" tools/finish_pcb.py
python tools/pipeline_pcb.py drc
python tools/check_layer_policy.py
python tools/check_schematic_parity.py
python tools/release_gate.py
```

若 `release_gate.py` 因生成器/config 比产物更新而报 stale，这是预期行为：重新生成对应产物，不要改 gate 时间戳逻辑绕过。

## 3. Experiment B 运行要求

至少跑 3 次独立 Freerouting run。每次必须从同一份 fresh DSN 开始，不允许以上一轮 SES 为输入继续优化。

固定参数：

```text
signal width = 0.20mm
clearance = 0.15mm
via = 0.40/0.20mm
In1 = GND only
In2 = +3V3 + explicit ordinary-GPIO whitelist
critical/semantic nets = F/B only
-mt = 1
```

记录每次：

- `max_passes`
- Freerouting completion marker
- unconnected count
- KiCad DRC error count
- clearance errors count
- via count（若现有脚本可直接获得）
- 总走线长度（若现有脚本可直接获得）
- runtime

不要只记录最好的一次。提交 `min / median / max` 或三次原始结果。

## 4. 允许本地 Agent 做的修改

只允许与“运行环境/重建产物/结果采集”直接相关的小修：

- KiCad/Freerouting 命令路径兼容；
- 结果日志/统计脚本；
- 由生成链自然产生的 `.sch/.net/.dsn/.ses/.pcb/.drc.json`；
- `build_status.json` 实际运行结果。

遇到以下情况不要自行改变设计规则，应记录并提交，由 GitHub 侧审查决定：

- 想放宽 clearance / via / layer policy；
- 想把更多语义网加入 In2 白名单；
- 想新增 waiver；
- 想改 DRC/parity/release gate 判定；
- 想改层叠结构或换双 GND/6 层。

## 5. 本批次验收

提交必须包含真实运行证据，至少：

```text
check_netlist output
Freerouting run #1/#2/#3 summary
KiCad DRC summary for each run or selected final run
check_layer_policy output
check_schematic_parity output
release_gate output
```

如果仍无法达到 0 unconnected / 0 error，保持：

```text
WIP / NOT FAB-READY
release_gate = BLOCKED
```

不要生成或提交“可投板”结论。

## 6. 下一轮审查输入

本地 Agent 推送后，下一轮 GitHub 侧审查重点比较：

1. 修正 0.20mm 后 B 实验是否显著优于旧 0.50mm 污染结果；
2. 3 次 run 的方差到底有多大；
3. 剩余未连通是随机收敛问题还是固定拓扑瓶颈；
4. In2 白名单是否实际触发了违规或产生电源 plane 连续性风险；
5. 是否值得继续 4 层混合策略，还是建立 6 层参考基线。

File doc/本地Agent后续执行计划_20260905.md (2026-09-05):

# 本地 Agent 后续执行计划（2026-09-05）

> 目标：把当前仓库从“部分脚本已修、EDA 产物仍可能来自旧中间件”的状态，推进到**同一次构建、可追溯、全部门禁一致通过**的 Prototype Release Candidate。
>
> 本文只安排必须依赖本机 KiCad / Freerouting / pcbnew 的工作；能直接在 GitHub 侧安全完成的规则和检查器已在 `review/artifact-lineage-gates-20260905` 分支先行修改。

---

## 0. 先同步分支

```bash
git fetch origin
git switch review/artifact-lineage-gates-20260905
git pull
```

不要从旧 `kicad/*.net/.dsn/.ses/.pcb/.drc.json` 继续局部修补，先建立一次完整的新构建链。

---

## 1. P0：修复 schematic → netlist 的 artifact lineage

### 当前问题

最新 `gen_schematic.py` 已增加 TPS54331 SS 电容 C28，但仓库内当前 `.net` 仍来自旧生成路径，导致 PCB / DRC 中出现 `missing_footprint C28`。

### 要求

1. 明确并脚本化 KiCad 10 的 netlist 导出命令：

```text
current stm32h743_core.kicad_sch
        ↓
KiCad CLI export netlist
        ↓
current stm32h743_core.net
```

2. 每次 `gen_schematic.py` 后必须强制重新导出 `.net`，不允许“文件存在就复用”。
3. 导出后立即运行 `tools/check_netlist.py`。
4. `check_netlist.py` 现在已把以下规则设为 hard requirement：

```text
SS = { U2.4, C28.1 }
GND contains C28.2
```

5. 新 `.net` 中必须能看到 C28 component 与 SS network。

### 验收

- `check_netlist.py` PASS；
- `.net` source 指向当前正式 schematic，而不是历史 `work_rebuild` 路径；
- C28 不再只存在于 `.kicad_sch`。

---

## 2. P0：消除规格书内部 SS 自相矛盾

当前规格书 §2.1 已改成：SS 外接 C28=10nF；但 §2.3 仍残留“SS 悬空 / 内部软启动”的旧描述。

本地 Agent 应：

1. 全仓搜索：

```bash
rg -n "SS.*悬空|内部软启动|内部默认斜率|C28|slow.?start|慢启动" .
```

2. 所有 TPS54331 SS 规则统一为：

```text
U2.4 SS -> C28 10nF -> GND
TI TPS54331 §7.3.5：内部没有 slow-start time，推荐外接 CSS
```

3. 不允许 Markdown 同一真源文件中出现两种互相冲突的规则。

---

## 3. P0：从新网表完整重建 PCB

完成 1/2 后，从零重跑：

```text
schematic
  ↓
netlist
  ↓
gen_pcb
  ↓
DSN layer classes
  ↓
Freerouting
  ↓
SES import / zones
  ↓
KiCad DRC --schematic-parity
```

禁止手工把 C28 直接补进旧 `.kicad_pcb` 作为最终修复；C28 必须由网表 → PCB 生成链自然进入。

C28 放置应靠近 U2 SS 引脚，SS 节点短，不要穿越 PH 开关节点区域。

---

## 4. P0：执行新的统一 Release Gate

本分支新增：

```text
tools/release_gate.py
```

当前 gate 包含：

1. `.net` 时间不得早于 `.kicad_sch`；
2. `drc.json` 不得早于 schematic / PCB；
3. `check_netlist.py`；
4. `check_layer_policy.py`；
5. KiCad DRC 必须 0 error / 0 unconnected；
6. `check_schematic_parity.py`。

Parity gate 现在会额外阻断：

```text
missing_footprint
```

因此当前旧 PCB 中的 C28 缺失会被正确拦截。

### 本地验证后继续做

确认上述 gate 在本机工作稳定后，把 `pipeline_pcb.py fab` 改成 fail-closed：

```text
fab_outputs()
    ↑
必须先 release_gate PASS
```

不能再允许直接执行 fab 绕过 semantic / layer / parity gate。

建议最后保留一个显式逃生参数仅用于调试，例如 `--unsafe-export`，默认绝不启用，并在输出中打印醒目警告。

---

## 5. P1：继续收敛机器可读的单一真源

本分支已经先把 `project_config.py` 中关键值调整为当前规格：

```text
BOARD = 85 x 65 mm
clearance = 0.15 mm
signal width = 0.20 mm
power width = 0.50 mm
via = 0.40 / 0.20 mm
plane policy:
  In1.Cu -> GND only
  In2.Cu -> +3V3 only
```

并让 `check_layer_policy.py` 直接读取 `PLANE_POLICY`。

本地 Agent 接下来要消除其余重复字面量：

- `gen_pcb.py` 中 0.5/0.25、0.4/0.2 混用；
- `.kicad_pro` netclass 生成中的 via/width；
- `pipeline_pcb.py` LAYER_PLAN 中 power width 0.30 与规格 ≥0.50 的冲突；
- 顶部历史注释“板 75x55mm”；
- 文档中的工艺规则。

目标：board geometry / fabrication limits / layer policy 尽量只从 `project_config.py` 或后续结构化配置读取。

---

## 6. P1：层策略不要直接改成“双 GND”来解决布线拥塞

当前 WIP 文档方案 1 提议：

```text
F / GND / GND / B
```

但如果普通信号仍只允许 F/B，这不会增加信号布线容量，反而让 +3V3 也更多占用 F/B。

因此本地 Agent 不应把“双 GND”作为“更容易自动布通”的默认结论。

建议做两个可比较实验：

### A. 严格 4 层基线

```text
F      Signal
In1    solid GND
In2    +3V3 plane
B      Signal
```

记录：未连通数、DRC error、Freerouting passes、via 数、总线长。

### B. 受控混合 L3

```text
F      critical/high-speed signal + local power
In1    solid GND (hard invariant)
In2    +3V3 pour + approved low-speed GPIO
B      general signal
```

约束：

- In1 永远禁止普通信号；
- USB / clock / SWD 等关键网禁止进入 In2；
- In2 只对白名单低速 GPIO 开放；
- +3V3 保留连续性门禁，不能被切成不可接受的窄颈/孤岛。

比较 A/B 后再决定正式层策略。

如果实验目标允许增加层数，再建立 6 层参考基线，而不是凭感觉判断 4 层策略优劣。

---

## 7. P1：README 当前状态必须自动或半自动更新

当前 README 仍存在历史“0 error / 0 未连通 / Gerber 可投板”的描述，而当前 WIP 明确不是这个状态。

本地重跑前先改成：

```text
CURRENT STATUS: WIP / NOT FAB-READY
```

最终只有 `release_gate.py` PASS 后才能恢复：

```text
Prototype Release Candidate
DRC: 0 error / 0 unconnected
Layer policy: PASS
Netlist: PASS
Parity: PASS
```

建议后续让流水线生成 `kicad/build_status.json`，README 只展示该文件结果，减少人工状态漂移。

---

## 8. P2：为门禁增加负测试

至少加入以下 fixtures / mutation tests：

| 故意错误 | 期望拦截门禁 |
|---|---|
| 删除 C28 | netlist / parity |
| U2.4 悬空 | netlist |
| PD13 走 In1.Cu | layer policy |
| PCB 缺一个 schematic footprint | parity |
| `.net` 比 `.sch` 旧 | release artifact lineage |
| PCB 有 1 条未连通 | DRC/release |
| zone 回退到 75×55 | geometry gate（待新增） |

只有门禁能主动抓住已知坏例，才算真正建立验证能力。

---

## 9. 本轮 GitHub 侧已经完成

`review/artifact-lineage-gates-20260905` 已完成：

- `project_config.py`：统一当前 board/fab/layer 关键参数；
- `check_netlist.py`：SS/C28 成为 hard requirement；
- `check_schematic_parity.py`：`missing_footprint` 变为 fatal，并归一化 `<no net>` / `unconnected-*`；
- `check_layer_policy.py`：从共享 `PLANE_POLICY` 读取；
- `release_gate.py`：新增 fail-closed release gate；
- 本文：记录必须依赖本地 KiCad/Freerouting 的剩余执行顺序。

本地 Agent 完成后，请提交实际运行结果，不只提交代码；至少附：

```text
check_netlist output
layer_policy output
KiCad DRC summary
parity output
release_gate output
Freerouting completion/unconnected summary
```

这样下一轮审查可以基于事实继续，而不是根据“已完成”文字判断。

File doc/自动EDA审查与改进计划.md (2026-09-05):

# 自动 EDA 审查与改进计划

> 日期：2026-09-05  
> 适用分支：`review/agent-eda-audit-20260905`  
> 目的：把本轮人工复核发现的问题固化为 Agent 可继续执行的设计约束、门禁与待办，避免“DRC 0 error = 设计正确”的误判。

---

## 1. 项目定位与本轮审查原则

本项目的核心目标不是单独做出一块 STM32H743 核心板，而是验证一条 **由 Agent 驱动、可复跑、可审计的自动 EDA 流水线**：

```text
官方数据手册 / 应用笔记 / 勘误
        +
有许可证可追溯的开源参考设计
        ↓
规格书（人审后的设计意图真源）
        ↓
原理图生成
        ↓
独立网表门禁
        ↓
PCB 预布局 / 自动布线
        ↓
DRC / 物理规则 / 设计意图门禁
        ↓
制造文件
        ↓
人工视觉复核 + 首板 bring-up
```

本轮复核继续沿用项目原有的“真源链 + 独立门禁”思想，但增加一条重要原则：

> **独立门禁不仅要验证“生成结果与规格一致”，还必须验证“规格本身与权威资料一致”。**

否则会出现“规格写错 → 生成器忠实执行 → 检查器忠实验证 → 全部 PASS”的自洽错误。

---

## 2. 本轮确认的问题

### P0-1：TPS54331 SS 处理规则错误

当前规格书将 `EN / SS` 一并定义为悬空，`gen_schematic.py` 也不连接 U2.4，`check_netlist.py` 进一步把“U2 的 EN/SS 应悬空”写成门禁。

这不是单点漏画，而是 **错误设计知识贯穿了规格 → 生成 → 验证整条链**。

依据：

- 仓库内：`doc/TPS54331_数据手册.pdf`
- TI TPS54331 Rev.H，Programmable Slow Start Using SS Pin：器件内部没有实现 slow-start 时间，建议在 SS 到 GND 外接电容；推荐 slow-start 1~10 ms，CSS 不超过 27 nF。
- EN 悬空可默认使能，但在 `VIN <= VOUT + 2V` 一类低压差输入条件下，TI 建议考虑外部 UVLO 滞回网络。

建议修复：

1. 规格书改为：`EN` 可悬空默认使能；`SS` 必须外接 CSS。
2. 首版建议 CSS = 10 nF 到 GND，约 4 ms slow-start。
3. `gen_schematic.py` 增加 SS 电容。
4. `check_netlist.py` 改为检查 U2.4 → CSS → GND，U2.3 才允许悬空。
5. 增加“关键器件特殊脚规则”检查表，不能只靠人工记忆。

状态：**本分支仅记录并建立后续门禁方向，原理图改动留给下一轮 Agent 与规格书同步完成。**

---

### P0-2：L2/L3 的“设计意图”没有被自动布线器遵守

规格书定义：

- L1：Signal + Components
- L2：完整 GND plane，不分割、不允许信号穿越
- L3：3.3V Power plane
- L4：Signal

但当前最终 PCB 中，`In1.Cu` 和 `In2.Cu` 都存在大量普通 GPIO / USB 信号线段。

这会造成：

- L2 地平面被 clearance 槽切碎；
- 高速/快速边沿信号回流路径被迫绕行；
- L3 3V3 plane 也被信号切割；
- 即使 clearance / short / unconnected 都是 0，仍然不满足原始叠层设计意图。

**关键结论：传统 DRC 只能证明“几何合法”，不能证明“设计意图合法”。**

建议：

1. 自动布线层策略改成：普通 Signal 仅允许 F.Cu / B.Cu。
2. In1.Cu 只允许 GND；In2.Cu 只允许 +3V3（或明确列出的电源网络）。
3. 增加独立 `layer policy gate`，扫描最终 `.kicad_pcb`，发现普通信号进入 plane layer 直接失败。
4. 对 USB、晶振、时钟等关键网络增加更窄的可用层集合。

状态：**本分支新增层策略门禁脚本；当前旧 PCB 预期会被该门禁拦截。自动布线器层约束调整留给后续 Agent。**

---

### P0-3：85×65 mm 板框与 75×55 mm plane zone 不一致

`gen_pcb.py` / `project_config.py` 的板尺寸是 85×65 mm，但 `finish_pcb.py` 中 zone 顶点被硬编码为 75×55 mm。

结果是内层 GND / 3V3 平面只覆盖左上 75×55 mm 区域，右侧和底部各缺 10 mm。

这属于明确的自动化脚本 bug。

状态：**本分支已修复 `finish_pcb.py`，zone 使用 `project_config.BOARD_W / BOARD_H`，不再硬编码尺寸。**

---

### P0-4：原理图与 PCB parity 没有进入最终放行条件

当前 `pipeline_pcb.py` 的 DRC 退出码只统计：

- `violations`
- `unconnected_items`

没有把 `schematic_parity` 的实质性错误纳入失败条件。

当前 committed `drc.json` 中已经能看到大量 parity warning，其中有两类：

1. **可归一化噪声**：PCB `PD14` vs 原理图 `/PD14`，仅层级前缀不同；
2. **真实不一致**：例如 PCB pad 网络与原理图目标网络不同。

因此不能简单把所有 parity warning 都设为 fatal，而应该做语义归一化后再判断。

状态：**本分支新增 `tools/check_schematic_parity.py`，对 `net_conflict` 做网络名归一化，只对实质不同的网络映射失败。**

后续建议进一步让 PCB 生成器保留 KiCad 层级网络名，减少 parity 噪声。

---

### P1-1：规格、配置、生成脚本之间出现参数真源漂移

当前至少存在：

- 规格书过孔：0.6 / 0.3 mm；
- `project_config.py`：0.6 / 0.3 mm；
- `gen_pcb.py`：0.5 / 0.25 mm；
- 规格书 3.3V / 5V 电源线：>=0.5 mm；
- `pipeline_pcb.py` Power class：0.3 mm。

这对“规格书唯一真源”的工程是不允许的。

建议：

1. 把 fabrication / board / layer policy 参数全部收敛到一个机器可读配置，例如：

```yaml
board:
  width_mm: 85
  height_mm: 65
stackup:
  In1.Cu: plane:GND
  In2.Cu: plane:+3V3
rules:
  clearance_mm: 0.15
  signal_width_mm: 0.20
  via_diameter_mm: 0.60
  via_drill_mm: 0.30
  power_width_mm: 0.50
```

2. Markdown 规格书由该配置生成规则摘要，或反过来从结构化 front matter 读取。
3. `gen_pcb.py`、`pipeline_pcb.py`、DRC gate 都从同一配置读取。
4. CI 增加 `config consistency gate`，禁止重复硬编码关键尺寸。

状态：待后续 Agent 实施。

---

### P1-2：去耦规则写进了规格书，但没有形成物理门禁

规格书要求每个 VDD 100 nF 靠近引脚，距离 <=3 mm，并要求良好的 GND 回路；当前动态布局算法默认把部分去耦中心放在 MCU pad 外约 4~4.5 mm。

建议把“去耦存在”升级成“去耦物理质量”门禁：

- 指定 MCU pin ↔ capacitor ref 的绑定；
- 计算 pad 到 pad 的欧氏距离 / 实际铜路长度；
- 对 VCAP、VDD33_USB、VDDA/VREF 分别设置阈值；
- 检查电容 GND pad 是否在限定半径内至少存在 N 个 GND via；
- 对 VCAP 禁止远端共用电容。

状态：待后续 Agent 实施。

---

## 3. 本分支已执行的改动

### 3.1 `finish_pcb.py`：修复 plane 尺寸硬编码

目标：所有 zone 边界使用统一板尺寸真源，不允许出现 `75×55` 这种历史残留常量。

### 3.2 新增 `tools/check_layer_policy.py`

功能：

- 扫描 `.kicad_pcb` 中所有 segment；
- In1.Cu 仅允许 GND；
- In2.Cu 仅允许 +3V3；
- 发现普通信号进入 plane layer 时退出非 0；
- 输出前若干违规网络与线段坐标，便于 Agent 定位。

该脚本对当前旧 PCB **预期失败**，这是正确行为：它把此前 DRC 看不到的设计意图转成了机器门禁。

### 3.3 新增 `tools/check_schematic_parity.py`

功能：

- 读取 `kicad/drc.json` 的 `schematic_parity`；
- 对 `net_conflict` 提取 PCB net / schematic net；
- 归一化前导 `/`；
- 仅当归一化后仍不同才报错。

目的：把“层级网络名前缀差异”与“真实网表错配”区分开。

---

## 4. 建议的自动门禁矩阵

后续流水线建议不再只有一个总称 DRC，而是显式分层：

| Gate | 输入 | 验证目标 | 失败是否阻断 |
|---|---|---|---|
| Reference gate | datasheet / AN / errata / reference design | 关键规则有权威出处且版本可追溯 | 是 |
| Pin truth gate | KiCad symbol + datasheet pin table | 引脚号/名字/电源域正确 | 是 |
| Schematic net gate | `.net` | 连通性、关键脚、悬空脚规则 | 是 |
| Schematic semantic gate | 规格 + 器件规则 | SS/EN/VCAP/BOOT/USB 等功能性规则 | 是 |
| Footprint gate | symbol + footprint | pin/pad mapping、封装、原点、同名 pad | 是 |
| Placement gate | `.kicad_pcb` | 去耦距离、晶振距离、DCDC 回路、边界 | 是 |
| Layer policy gate | `.kicad_pcb` | plane layer 不被普通信号切割 | 是 |
| Routing gate | `.kicad_pcb` | 线宽、过孔、关键网络层/长度 | 是 |
| KiCad DRC | `.kicad_pcb` | short/clearance/unconnected 等几何规则 | 是 |
| Parity gate | schematic + PCB | 原理图与 PCB 语义一致 | 是 |
| Visual review | PDF / PNG / 3D | 丝印、可制造性、布局合理性 | 首板前是 |
| Bring-up gate | 实板 | 电源、VCAP、时钟、SWD、DFU | 量产前是 |

---

## 5. Agent 后续执行顺序

建议下一轮不要直接“修最终 PCB”，而是按真源向下修：

```text
1. 更新规格书
   ├─ TPS54331 SS
   ├─ EN / UVLO 策略
   ├─ 结构化 stackup / fabrication 参数
   └─ 明确 plane-layer 禁止信号

2. 更新原理图生成器
   └─ SS 外接电容 + 对应器件规则

3. 更新网表门禁
   └─ U2.4 不再允许悬空

4. 更新 PCB 生成 / 自动布线规则
   ├─ F/B only signal routing
   ├─ In1 = GND plane
   ├─ In2 = +3V3 plane
   └─ USB / clock 单独规则

5. 重跑 PCB

6. 运行全部 gate
   ├─ check_netlist
   ├─ check_layer_policy
   ├─ KiCad DRC
   ├─ check_schematic_parity
   └─ placement / decoupling gate（新增）

7. 重新生成 Gerber / Drill / BOM / POS

8. 人工终审
```

**禁止**只修改 `kicad/stm32h743_core.kicad_pcb` 或 Gerber 来“修绿”，因为那会破坏可复跑性。

---

## 6. 对 Agent 工作流的进一步建议

### 6.1 每条关键规则都带 provenance

建议将规则记录成：

```text
rule_id: TPS54331.SS.external_cap
source: doc/TPS54331_数据手册.pdf
section: 7.3.5
requirement: SS must have external capacitor to GND
status: verified
```

生成器与检查器都引用 `rule_id`，而不是各自在注释里写一遍自然语言。

### 6.2 生成器和检查器不能共用同一个“事实表”完成自证

允许共用：

- 文件路径
- 单位换算
- 通用 parser

不建议共用：

- 关键网络期望节点
- 芯片特殊脚行为
- plane layer 使用策略

检查器应该从独立的规则/规格输入得到期望结果。

### 6.3 自动流程必须有“负测试”

每个 gate 至少准备一个故意错误的 fixture：

- 把 VCAP 接错 → net gate 必须失败；
- 把 PD13 放到 In1.Cu → layer policy gate 必须失败；
- 把 PCB R25 pad1 改成 PB0 而 schematic 要 +3V3 → parity gate 必须失败；
- 把 plane 缩成 75×55 → geometry gate 必须失败。

只有能抓住已知错误的检查器，才算有效门禁。

### 6.4 DRC 0 error 的语义必须收窄

后续文档统一使用：

> `KiCad DRC 0 error` = 几何/连接规则通过，不代表电源完整性、回流路径、EMC、器件应用规则或制造可用性全部通过。

最终可投板状态建议定义成：

```text
Reference PASS
+ Schematic PASS
+ Semantic PASS
+ Placement PASS
+ Layer Policy PASS
+ DRC PASS
+ Parity PASS
+ Visual Review PASS
= Prototype Release Candidate
```

---

## 7. 当前阶段结论

这个项目已经证明 Agent 可以把 EDA 的大量机械工作自动化：引脚核验、原理图生成、网表检查、布局、自动布线、DRC、制造文件都能纳入脚本。

本轮暴露出来的主要瓶颈已经不是“Agent 会不会画板”，而是：

1. **设计知识是否可靠；**
2. **设计意图是否能被机器表达；**
3. **检查器是否真的独立；**
4. **传统 DRC 之外是否存在语义/物理质量门禁；**
5. **规格、配置、脚本、产物之间是否始终保持单一真源。**

下一阶段应优先增强这些“工程约束表达和验证能力”，而不是继续增加自动布线复杂度。

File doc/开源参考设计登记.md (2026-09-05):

# 开源参考设计登记

| 项 | 内容 |
|---|---|
| 登记日期 | 2026-09-04 |
| 用途 | STM32H743ZIT6 核心板项目的交叉验证（对照结论见《STM32H743ZIT6_核心板设计规格书》附录 B） |
| 检索范围 | ST 官方参考设计、GitHub 开源核心板、立创开源平台（oshwhub） |

## 1. 已保存到本地的文件

| 本地文件 | 来源 | 许可/版权 | 说明 |
|---|---|---|---|
| [NUCLEO-H743ZI2_MB1364_官方原理图.pdf](NUCLEO-H743ZI2_MB1364_官方原理图.pdf) | [ST 官网 CAD Resources](https://www.st.com/en/evaluation-tools/nucleo-h743zi.html#cad-resources) | ST 版权，仅供参考 | 同芯片（H743ZI）同封装（LQFP144）官方设计；VDD33_USB/VCAP/BOOT0/PDR_ON/LSE 的对照依据 |
| [WeAct_STM32H7xx_核心板_原理图_V12.pdf](WeAct_STM32H7xx_核心板_原理图_V12.pdf) | GitHub `WeActStudio/MiniSTM32H7xx` 的 `Hardware/` 目录 | 仓库整体 GPL-3.0 | 量产验证的低价核心板（H743VIT6/H750VBT6），USB-C + DFU 策略对照依据；配套 Altium 集成库与 3D STEP 未下载 |

## 2. 在线参考（未本地化）

| 名称 | 链接 | 说明 |
|---|---|---|
| WeActStudio/MiniSTM32H7xx | https://github.com/WeActStudio/MiniSTM32H7xx | H743VIT6 核心板仓库（Hardware/ 目录含原理图 PDF、Altium 库、3D 模型、旧版本）；README：2×22P 排针、USB-C、DFU/UART ISP、四层板、PC13 用户键 |
| WeActStudio 产品总览 | https://github.com/WeActStudio/WeAct-Studio-Product/blob/master/README-zh.md | 全系板卡资料入口 |
| oshwhub：STM32H743IIT6 开发板 | https://oshwhub.com/lixidixi/stm32h743iit6-development-board | LQFP176 + 256Mbit SDRAM，无调试口、DFU 下载，全 IO 引出 |
| oshwhub：STM32H743Ix/F767Ix 核心板 | https://oshwhub.com/micespring/stm32h743ii-coreboard | LQFP176 + SDRAM + QSPI NOR，原理图 PCB 均开源 |
| ST NUCLEO-H743ZI CAD 资源页 | https://www.st.com/en/evaluation-tools/nucleo-h743zi.html#cad-resources | 官方原理图 / EDA 数据库 / BOM 下载入口（ZI2 = MB1364 板型） |
| UM2407 用户手册 | https://www.st.com/resource/en/user_manual/um2407-stm32h7-nucleo144-boards-mb1364-stmicroelectronics.pdf | Nucleo-144（MB1364）板级手册，附录含原理图 |
| ST 社区：Nucleo-H743ZI2 原理图位置帖 | https://community.st.com/stm32-mcus-products-25/where-are-the-schematics-for-nucleo-h743zi2-11549 | 确认 ZI2 对应 MB1364 的线索 |

## 3. 复用注意

1. **ST 官方原理图**归 ST 版权所有——只作电路处理方式的对照，不可整页复用或照抄布局。
2. **WeAct 仓库为 GPL-3.0**——直接复用其图纸/PCB 源文件会引入 GPL 传染义务；本项目原理图/PCB 由脚本按自有规格书自动生成，仅做参数级对照，不构成其衍生作品。
3. **oshwhub 项目**按平台开源协议（CC 类）在线查看/克隆到嘉立创 EDA，导出需登录，故仅登记链接。
4. **网络备注**：`raw.githubusercontent.com` 在当前网络不可达（Connection reset）；从 GitHub 下载文件走 `api.github.com` 的 Git Blobs 通道（`Accept: application/vnd.github.raw`），已验证可用。
5. Altium 导出的 PDF 用 pypdf 提取不到元件值（矢量图形化），看具体参数需打开 PDF 人工查看。

## 4. 已完成对照项摘要（详见规格书附录 B）

- VDD33_USB → 3.3V 域：官方 Nucleo 板一致 ✓
- VCAP×2 / PDR_ON / BOOT0（电阻+选择器）：官方 Nucleo 板一致 ✓
- LSE 3215 封装 32.768kHz：官方 Nucleo 板一致（NX3215SA）✓
- USB-C 供电 + CC 上下拉 + DFU 下载 + PC13 用户键 + 四层板：WeAct 板一致 ✓
- HSE：Nucleo 用 ST-LINK MCO 馈入（调试器方案），WeAct/本设计用晶振——产品定位不同，本设计选 8MHz 晶振（与 DS12110 Figure 71 典型应用一致）

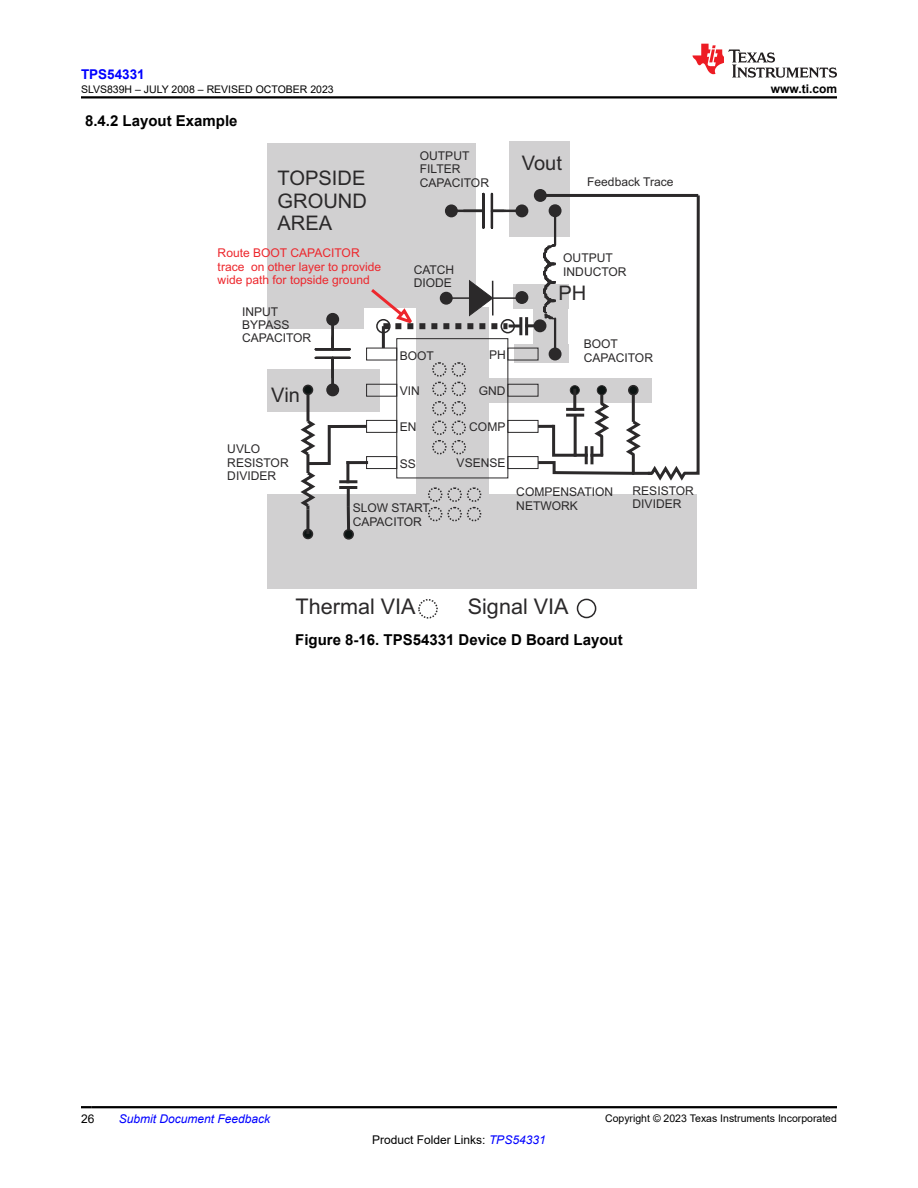
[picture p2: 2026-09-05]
doc/extracted/figures/TPS54331_数据手册_p26.png

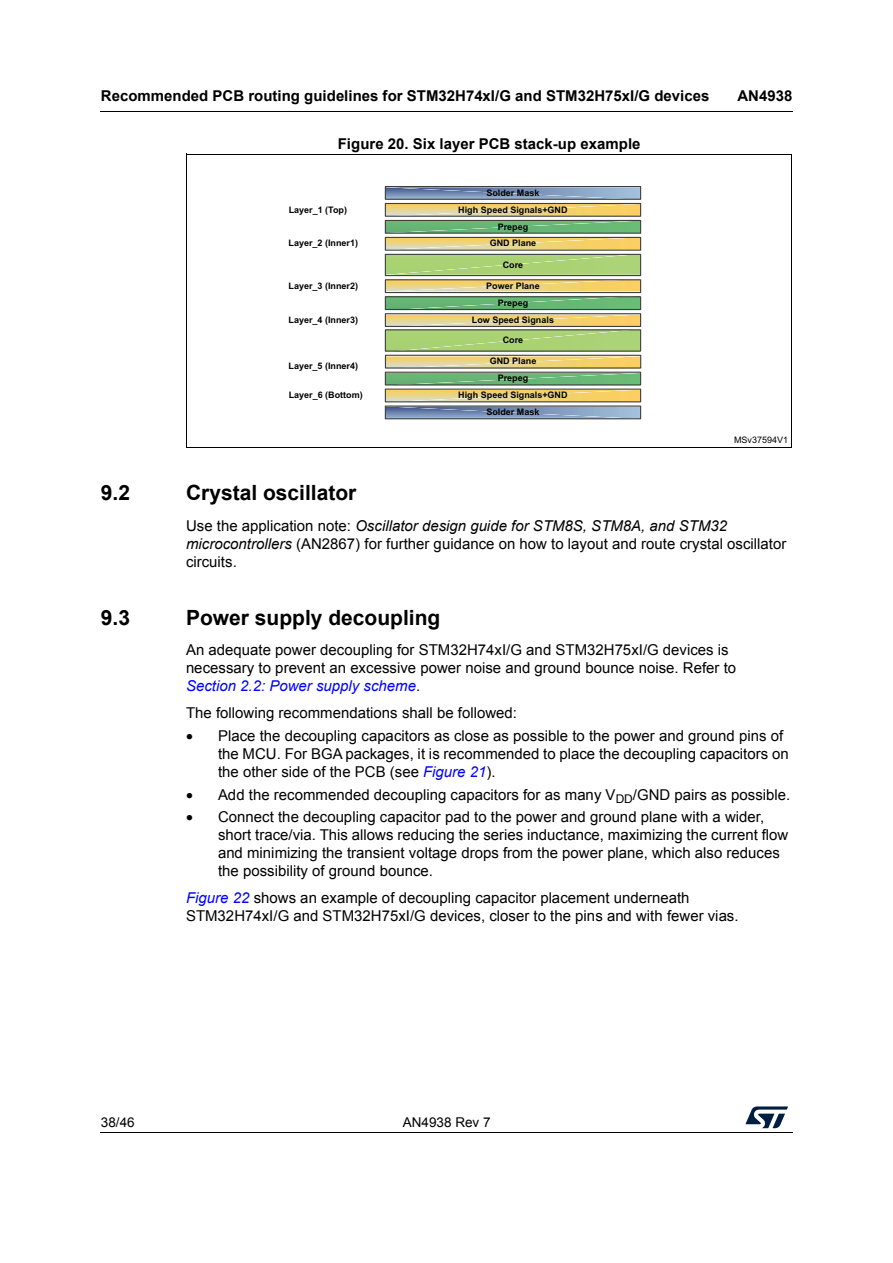
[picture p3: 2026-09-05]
doc/extracted/figures/AN4938_硬件开发入门_p38.png

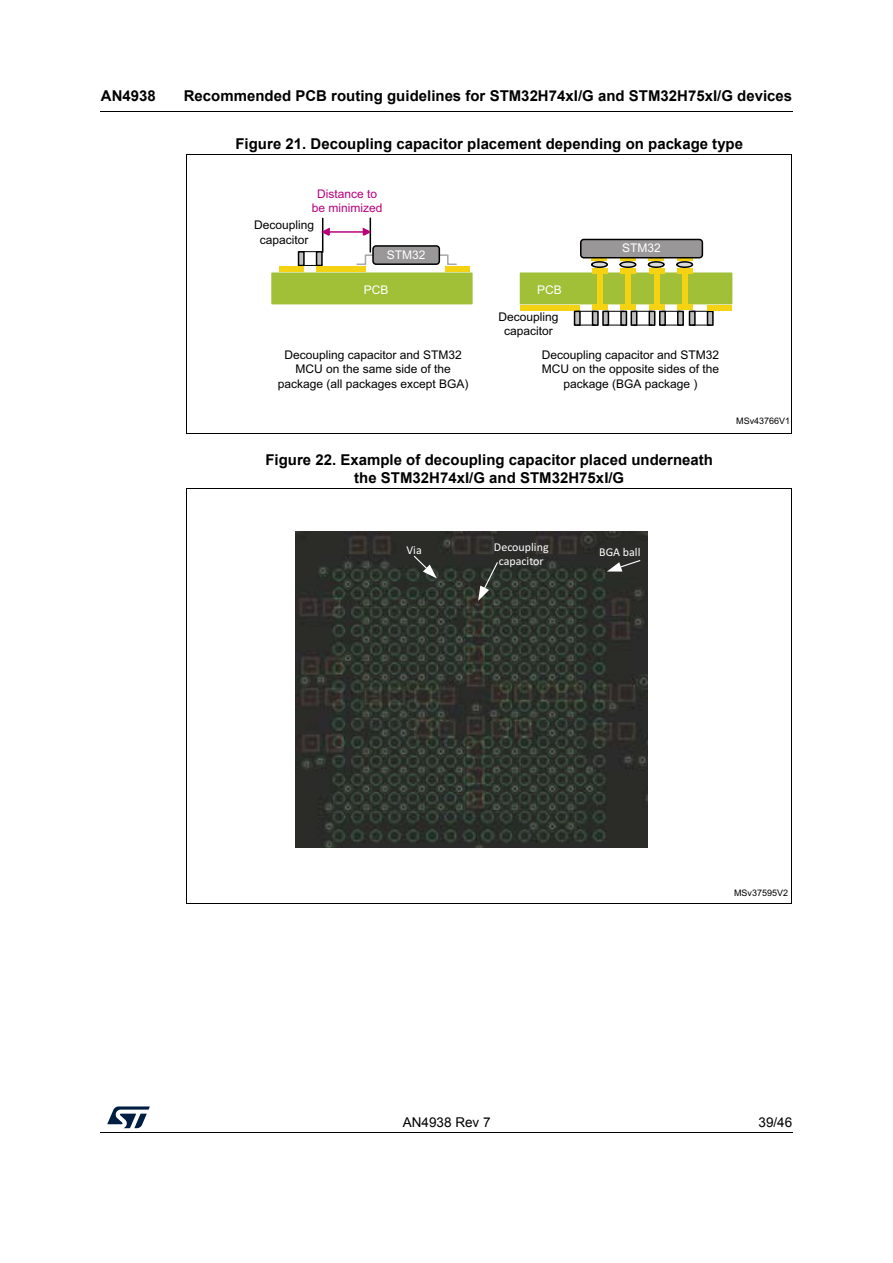
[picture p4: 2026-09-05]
doc/extracted/figures/AN4938_硬件开发入门_p39.png

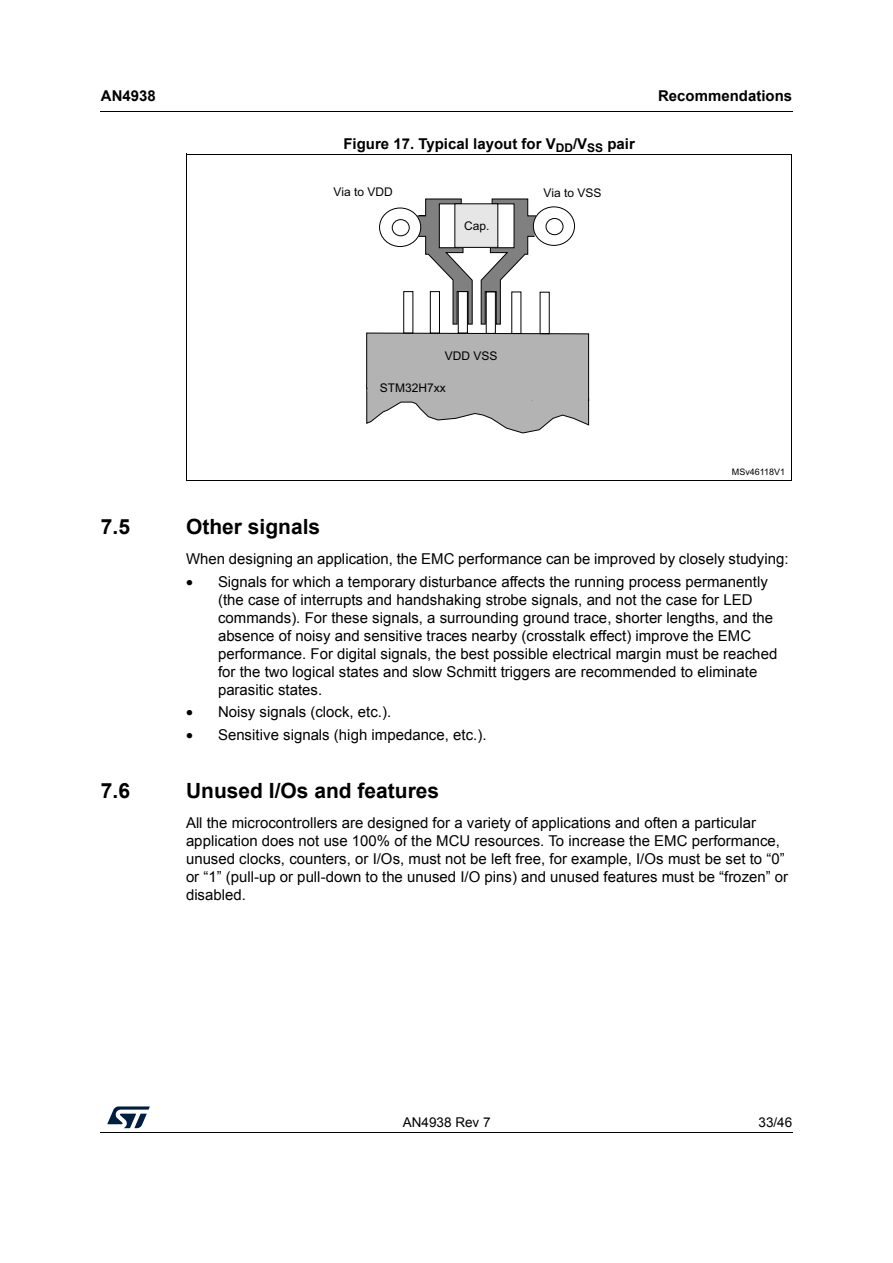
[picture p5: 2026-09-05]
doc/extracted/figures/AN4938_硬件开发入门_p33.png

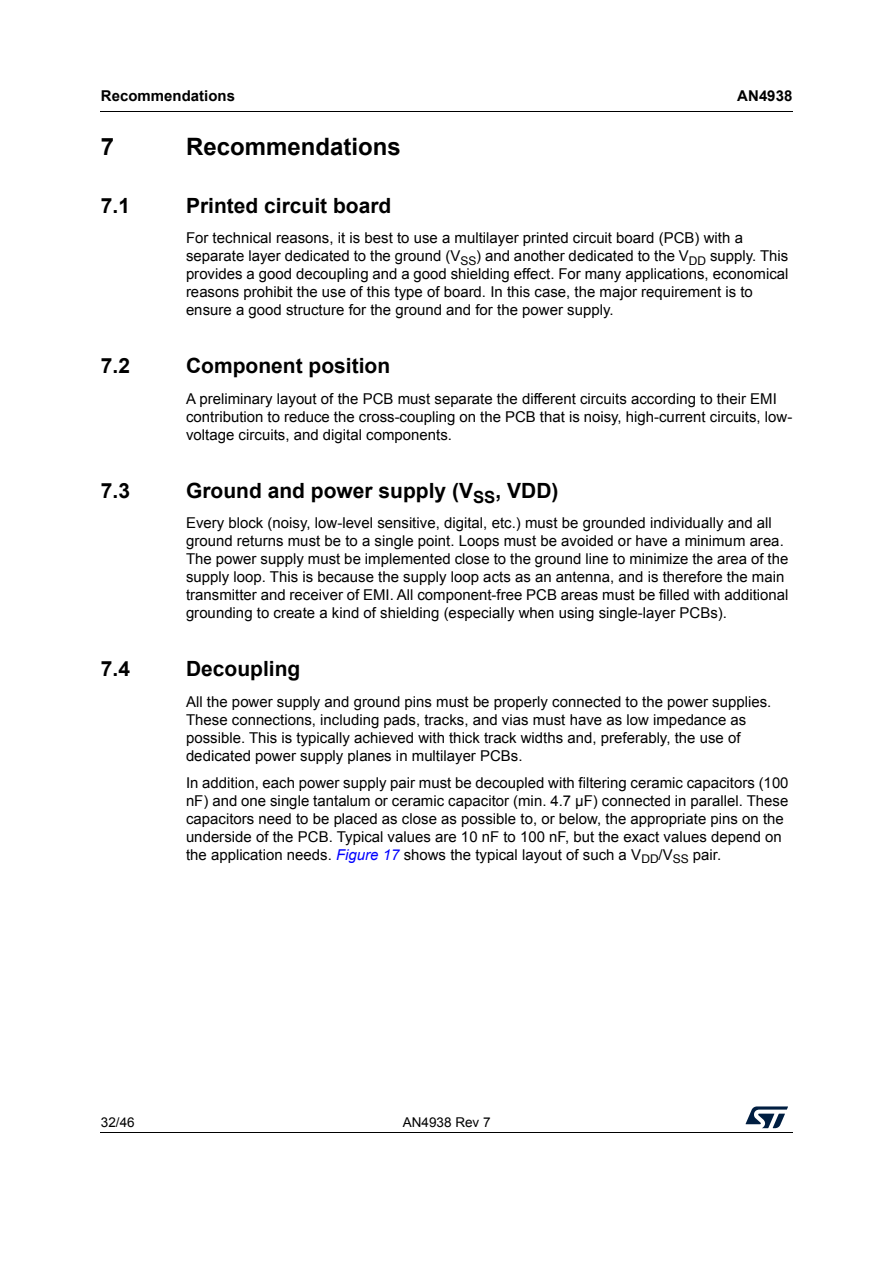
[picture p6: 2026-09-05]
doc/extracted/figures/AN4938_硬件开发入门_p32.png

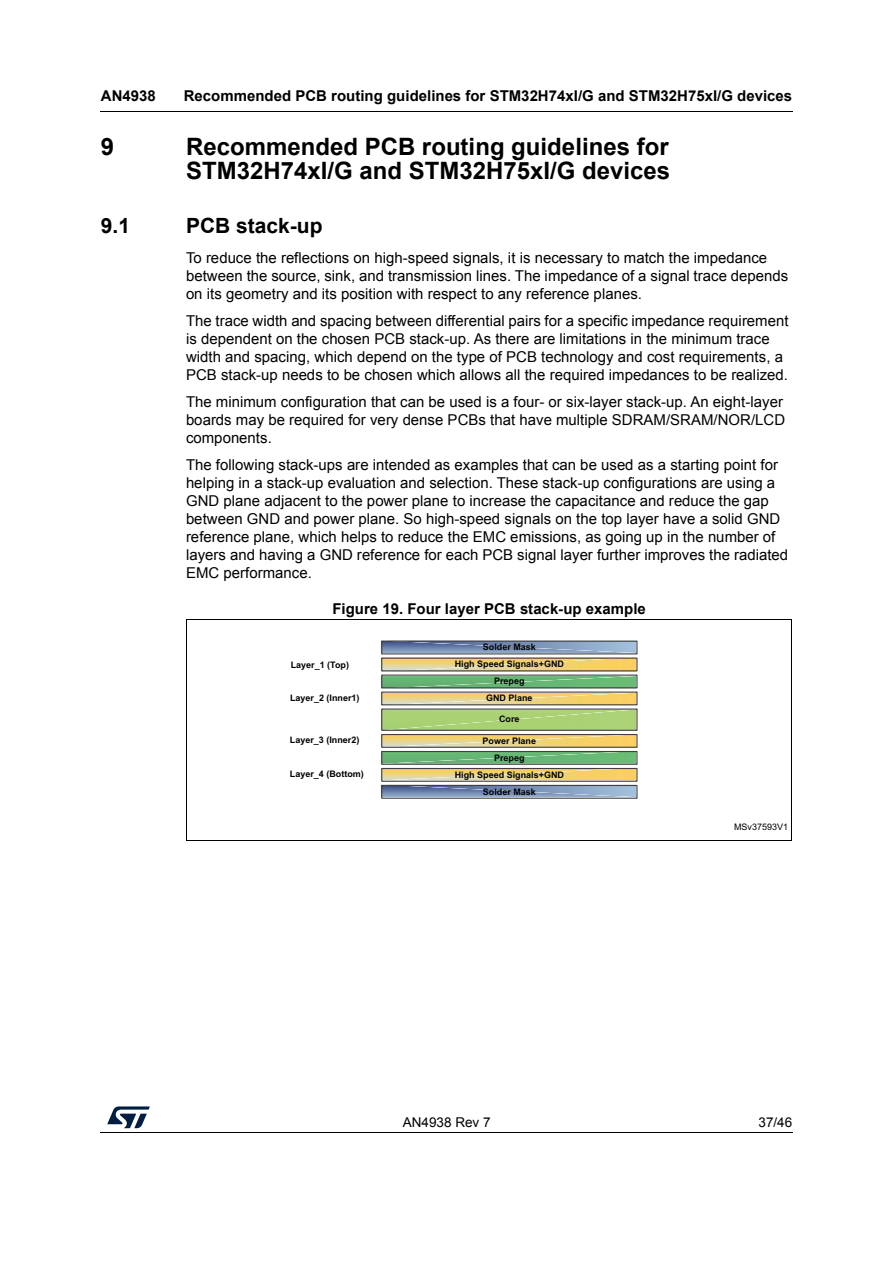
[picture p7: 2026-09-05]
doc/extracted/figures/AN4938_硬件开发入门_p37.png

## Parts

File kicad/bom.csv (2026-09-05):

Reference | Value | Footprint | QUANTITY
C20,C23,C45,C47 | 100n | Capacitor_SMD:C_0402_1005Metric | 4
C21,C22 | 10uF | Capacitor_SMD:C_0805_2012Metric | 2
C24,C25 | 47uF | Capacitor_SMD:C_1206_3216Metric | 2
C26 | 1nF | Capacitor_SMD:C_0402_1005Metric | 1
C27 | 47pF | Capacitor_SMD:C_0402_1005Metric | 1
C40,C41 | 2.2uF | Capacitor_SMD:C_0603_1608Metric | 2
C42,C44,C46 | 1uF | Capacitor_SMD:C_0603_1608Metric | 3
C43,C48,C54,C55,C60-C70 | 100nF | Capacitor_SMD:C_0402_1005Metric | 15
C50-C53 | 18pF | Capacitor_SMD:C_0402_1005Metric | 4
C71,C72 | 4.7uF | Capacitor_SMD:C_0603_1608Metric | 2
D5-D7 | SS34 | Diode_SMD:D_SMA | 3
D8 | PWR_GREEN | LED_SMD:LED_0603_1608Metric | 1
D9 | USER_BLUE | LED_SMD:LED_0603_1608Metric | 1
F1 | 500mA | Fuse:Fuse_1206_3216Metric | 1
FB1 | 600R@100MHz | Inductor_SMD:L_0603_1608Metric | 1
J1,J2 | GPIO | Connector_PinHeader_2.54mm:PinHeader_2x28_P2.54mm_Vertical | 2
J3 | USB_C | Connector_USB:USB_C_Receptacle_HRO_TYPE-C-31-M-12 | 1
J4 | SWD | Connector_PinHeader_2.54mm:PinHeader_1x06_P2.54mm_Vertical | 1
J5 | BOOT | Connector_PinHeader_2.54mm:PinHeader_1x03_P2.54mm_Vertical | 1
J6 | 5VIN | Connector_PinHeader_2.54mm:PinHeader_1x02_P2.54mm_Vertical | 1
L1 | 6.8uH/4A | Inductor_SMD:L_Bourns_SRP7028A_7.3x6.6mm | 1
R10,R11 | 5.1k | Resistor_SMD:R_0402_1005Metric | 2
R12 | 68k | Resistor_SMD:R_0402_1005Metric | 1
R13,R23 | 100k | Resistor_SMD:R_0402_1005Metric | 2
R14 | 0R | Resistor_SMD:R_0805_2012Metric | 1
R15 | 10.2k | Resistor_SMD:R_0402_1005Metric | 1
R16 | 3.24k | Resistor_SMD:R_0402_1005Metric | 1
R17 | 29.4k | Resistor_SMD:R_0402_1005Metric | 1
R20,R21 | 0R | Resistor_SMD:R_0402_1005Metric | 2
R22 | 10k | Resistor_SMD:R_0402_1005Metric | 1
R24,R25 | 1k | Resistor_SMD:R_0402_1005Metric | 2
SW1 | NRST_KEY | Button_Switch_THT:SW_PUSH_6mm | 1
SW2 | USER_KEY | Button_Switch_THT:SW_PUSH_6mm | 1
TP1 | +3V3 | TestPoint:TestPoint_Pad_D1.0mm | 1
TP2 | GND | TestPoint:TestPoint_Pad_D1.0mm | 1
TP3 | VCAP | TestPoint:TestPoint_Pad_D1.0mm | 1
TP4 | NRST | TestPoint:TestPoint_Pad_D1.0mm | 1
TP5 | BOOT0 | TestPoint:TestPoint_Pad_D1.0mm | 1
TP6 | 3V3_SW | TestPoint:TestPoint_Pad_D1.0mm | 1
U1 | STM32H743ZIT6 | Package_QFP:LQFP-144_20x20mm_P0.5mm | 1
U2 | TPS54331DDAR | Package_SO:SOIC-8-1EP_3.9x4.9mm_P1.27mm_EP2.29x3mm | 1
U3 | USBLC6-2SC6 | Package_TO_SOT_SMD:SOT-23-6 | 1
X1 | 8MHz | Crystal:Crystal_SMD_3215-2Pin_3.2x1.5mm | 1
X2 | 32.768kHz | Crystal:Crystal_SMD_3215-2Pin_3.2x1.5mm | 1

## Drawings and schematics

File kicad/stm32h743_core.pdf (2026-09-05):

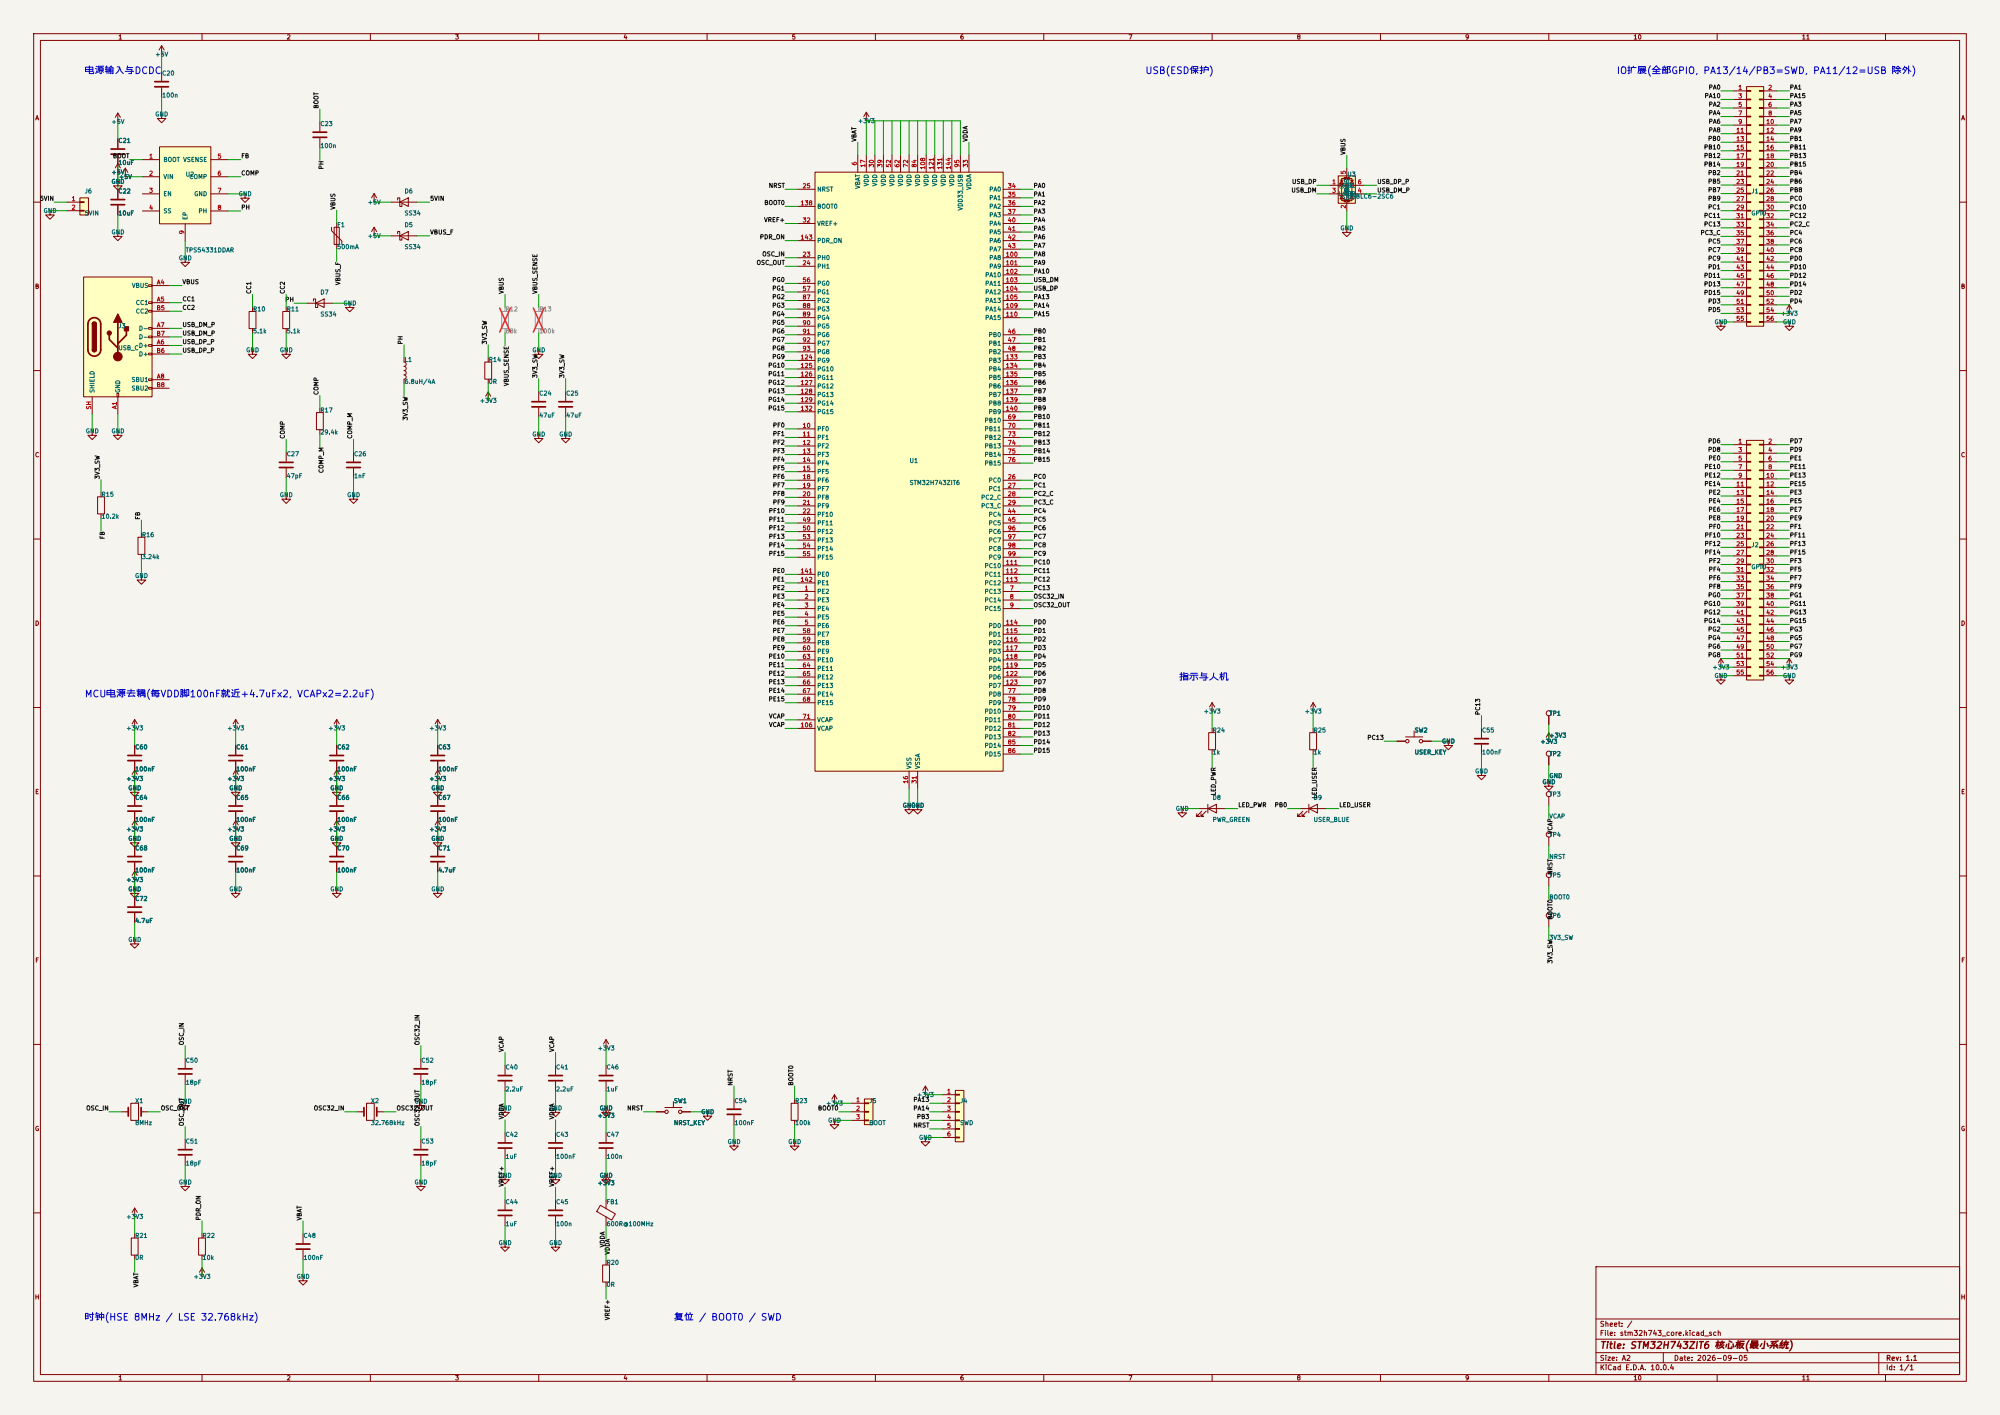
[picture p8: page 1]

Size: A2 | Rev: 1.1
KiCad E.D.A. 10.0.4 | Id: 1/1

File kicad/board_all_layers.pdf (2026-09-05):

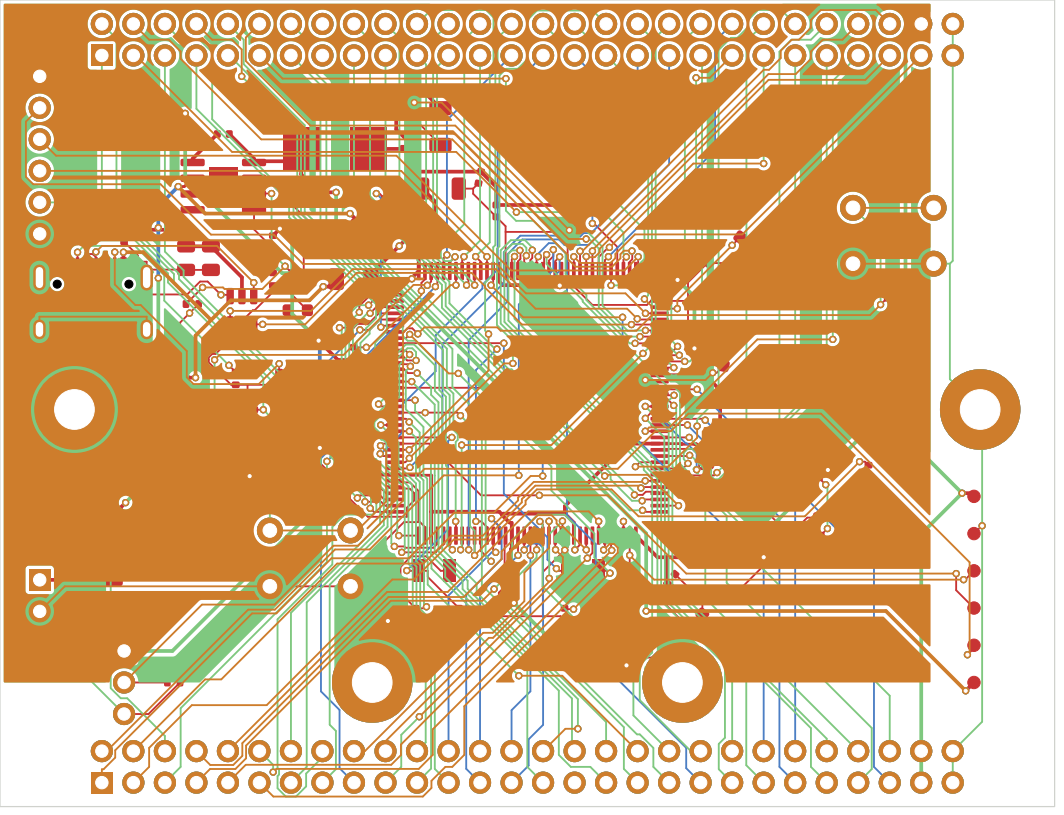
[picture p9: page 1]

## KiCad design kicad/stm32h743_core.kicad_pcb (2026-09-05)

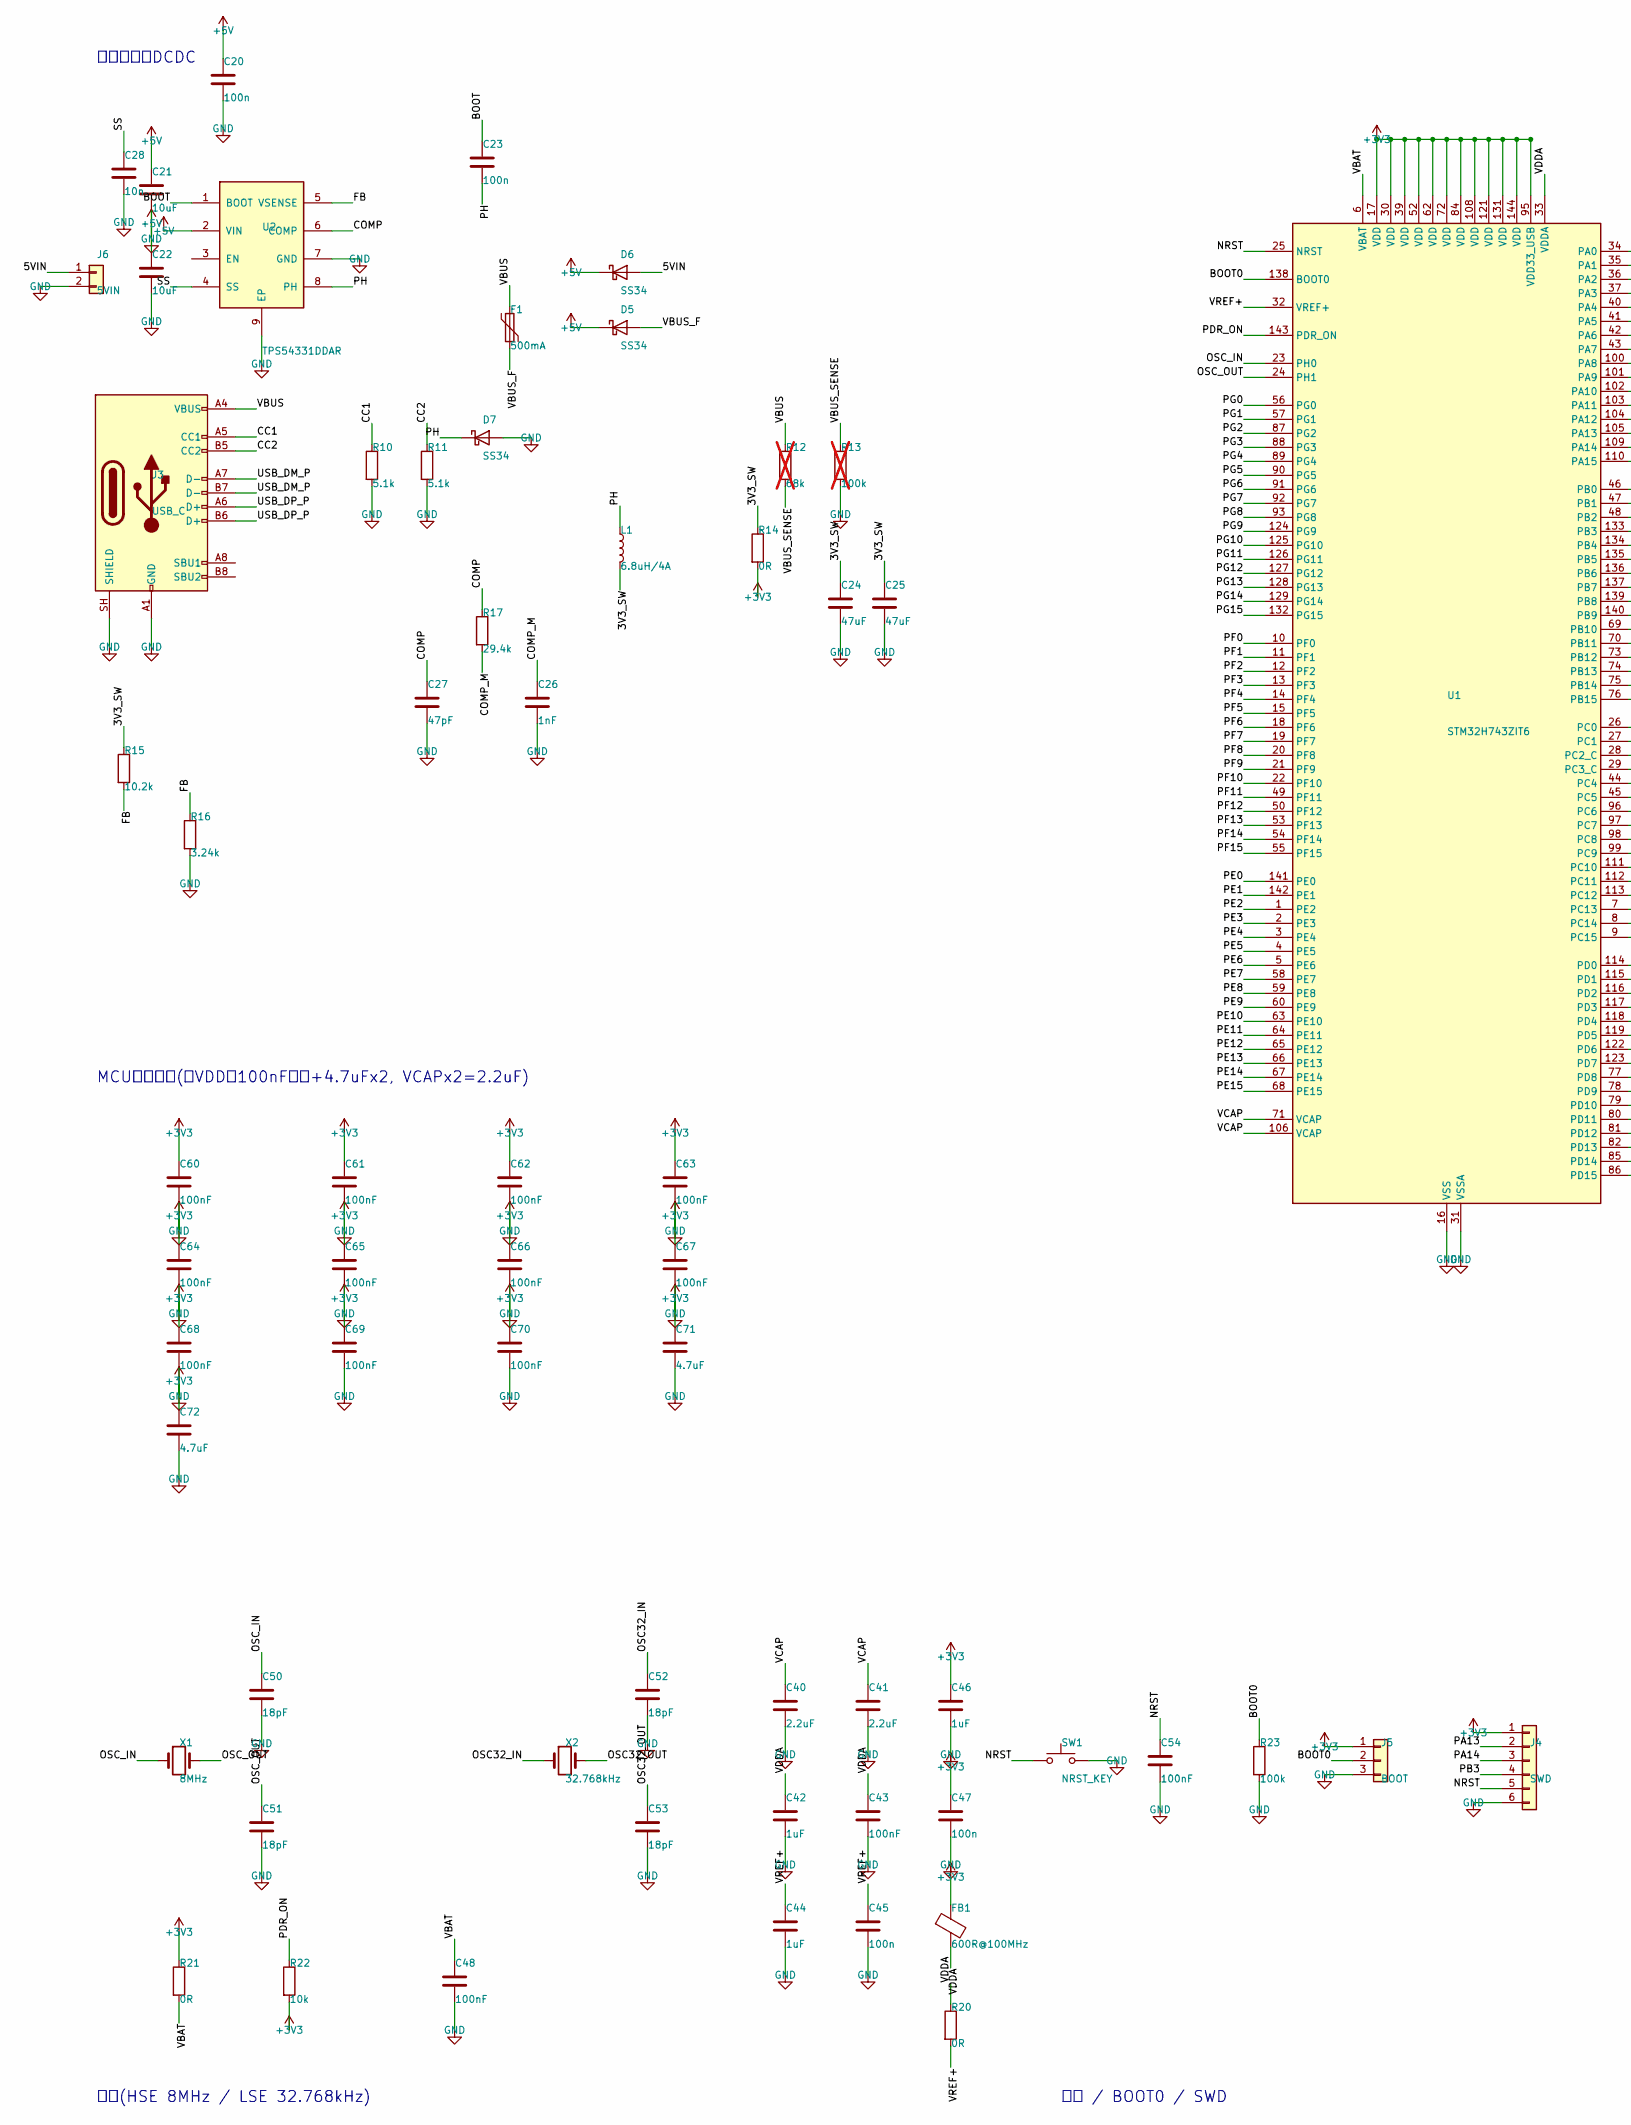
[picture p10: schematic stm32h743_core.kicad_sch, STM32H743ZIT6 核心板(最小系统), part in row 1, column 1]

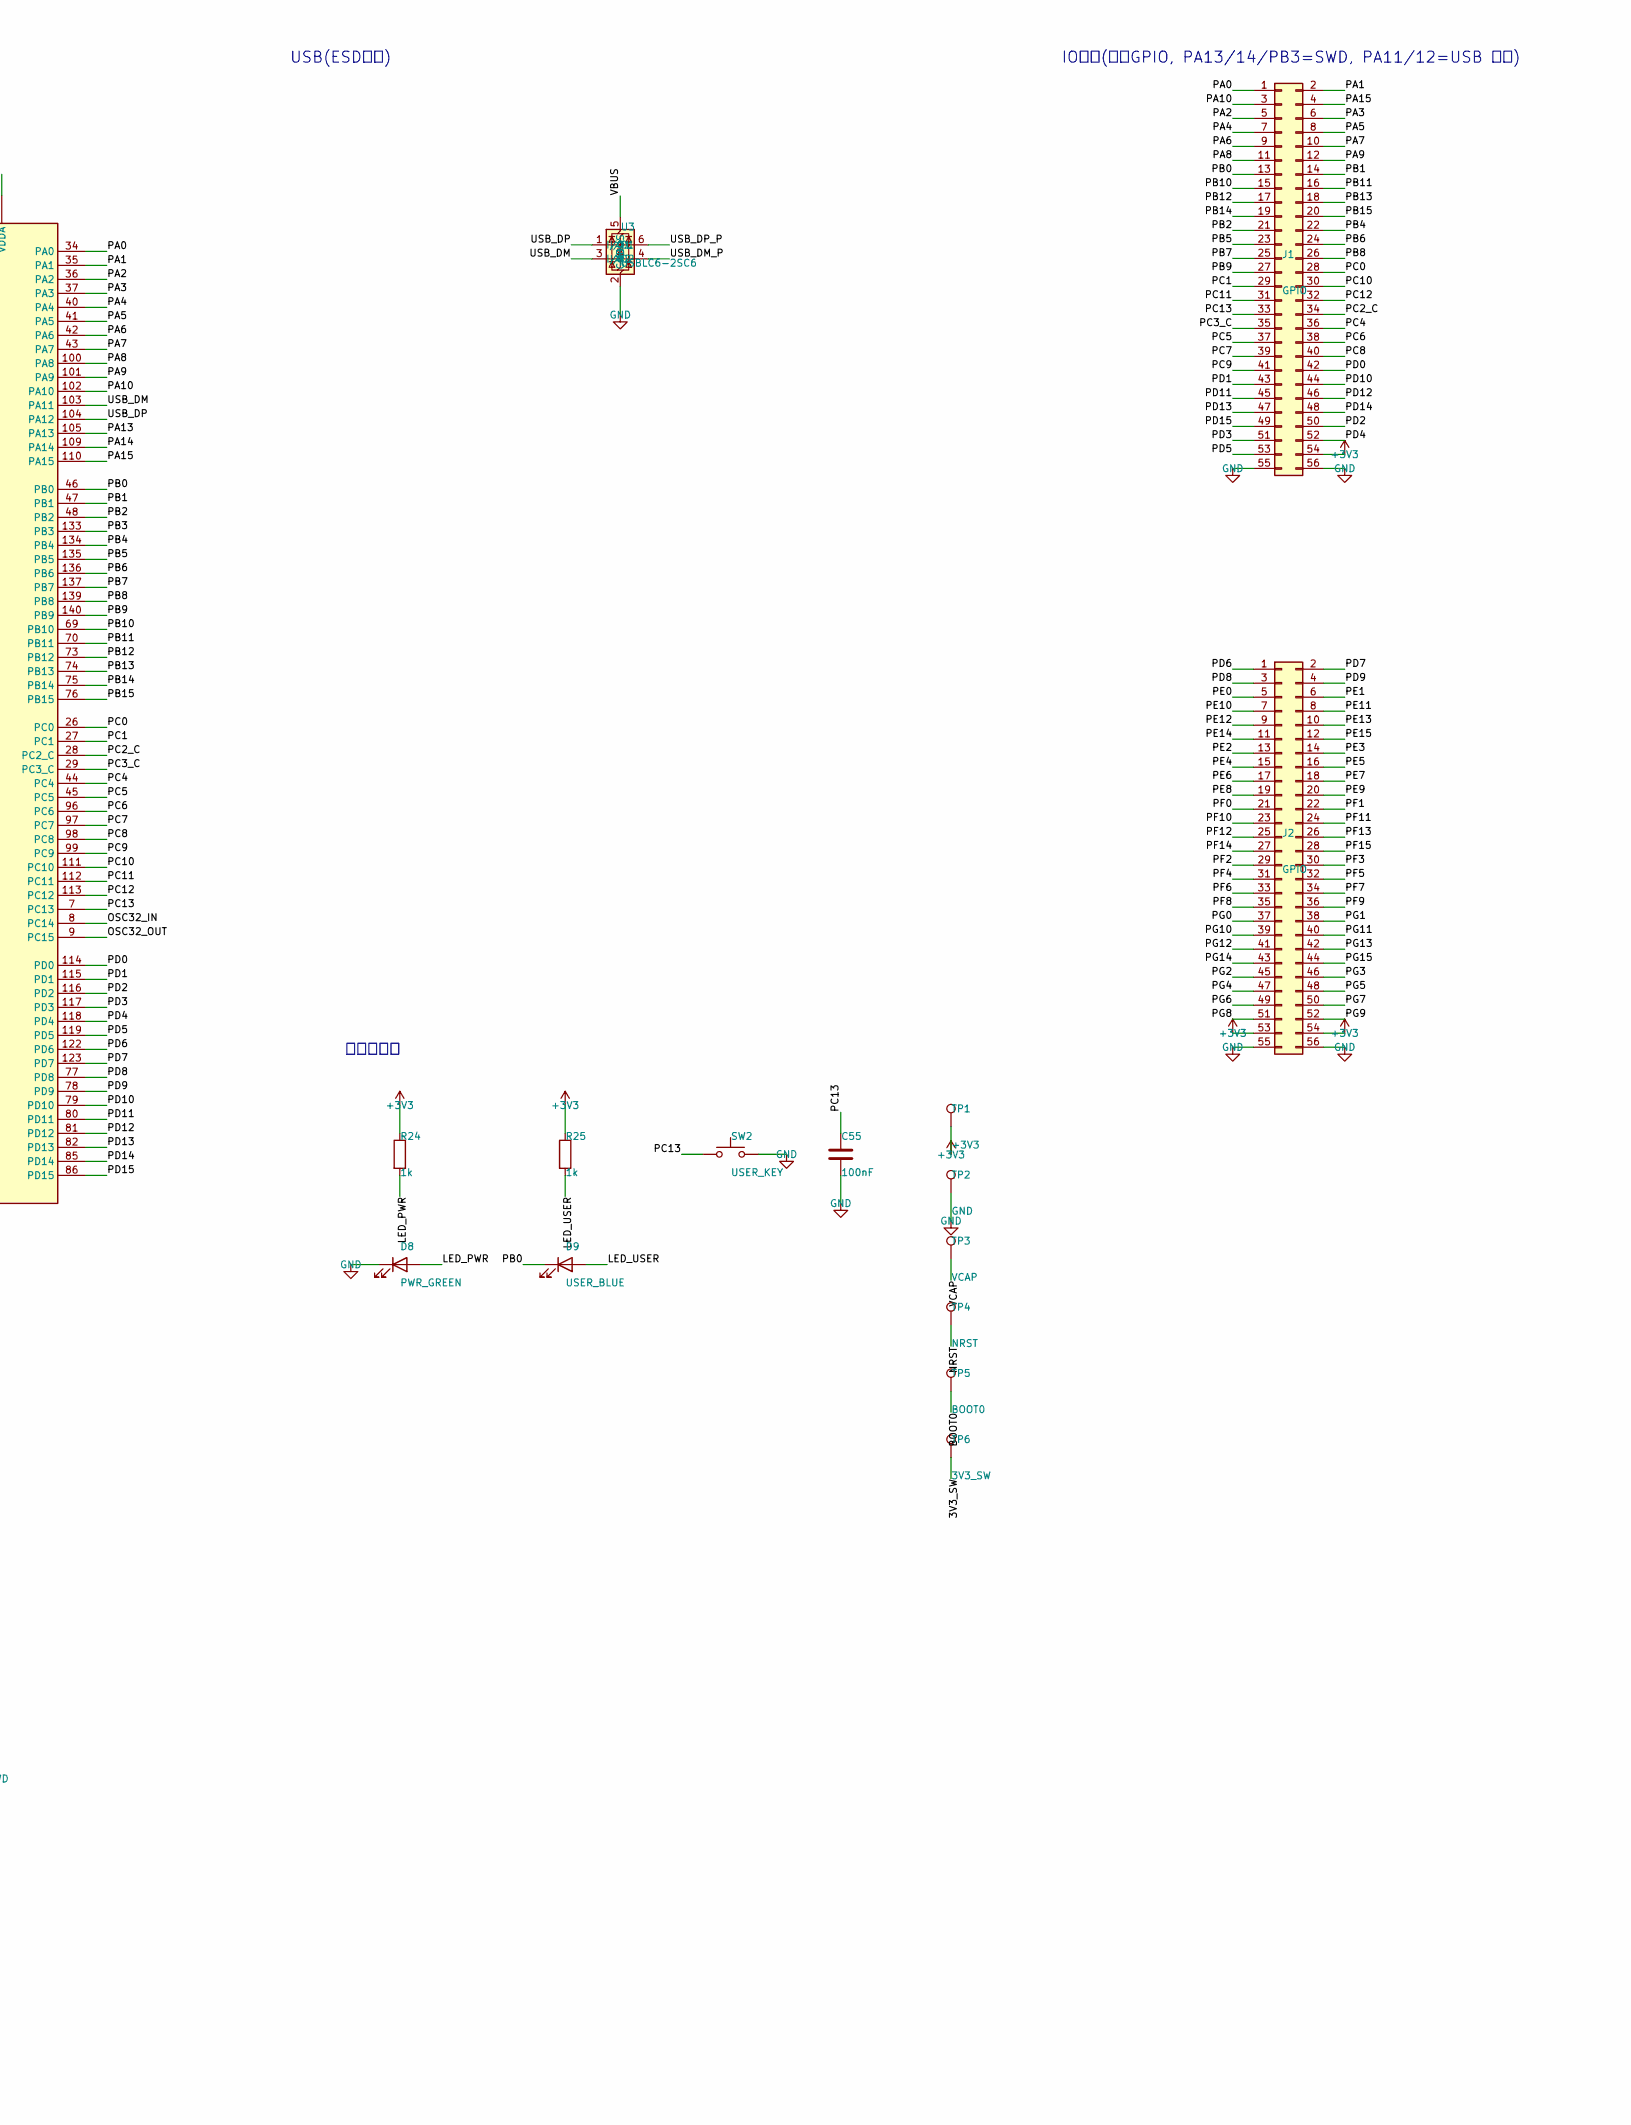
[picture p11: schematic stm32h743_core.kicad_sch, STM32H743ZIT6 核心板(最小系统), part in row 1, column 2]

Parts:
C20, C23, C45, C47: 100n; C_0402_1005Metric
C21, C22: 10uF; C_0805_2012Metric
C24, C25: 47uF; C_1206_3216Metric
C26: 1nF; C_0402_1005Metric
C27: 47pF; C_0402_1005Metric
C28: 10n; C_0402_1005Metric
C40, C41: 2.2uF; C_0603_1608Metric
C42, C44, C46: 1uF; C_0603_1608Metric
C43, C48, C54, C55, C60, C61, C62, C63, C64, C65, C66, C67, C68, C69, C70: 100nF; C_0402_1005Metric
C50, C51, C52, C53: 18pF; C_0402_1005Metric
C71, C72: 4.7uF; C_0603_1608Metric
D5, D6, D7: SS34; D_SMA
D8: PWR_GREEN; LED_0603_1608Metric
D9: USER_BLUE; LED_0603_1608Metric
F1: 500mA; Fuse_1206_3216Metric
FB1: 600R@100MHz; L_0603_1608Metric
J1, J2: GPIO; PinHeader_2x28_P2.54mm_Vertical
J3: USB_C; USB_C_Receptacle_HRO_TYPE-C-31-M-12
J4: SWD; PinHeader_1x06_P2.54mm_Vertical
J5: BOOT; PinHeader_1x03_P2.54mm_Vertical
J6: 5VIN; PinHeader_1x02_P2.54mm_Vertical
L1: 6.8uH/4A; L_Bourns_SRP7028A_7.3x6.6mm
R10, R11: 5.1k; R_0402_1005Metric
R12: 68k; R_0402_1005Metric; not fitted
R13: 100k; R_0402_1005Metric; not fitted
R14: 0R; R_0805_2012Metric
R15: 10.2k; R_0402_1005Metric
R16: 3.24k; R_0402_1005Metric
R17: 29.4k; R_0402_1005Metric
R20, R21: 0R; R_0402_1005Metric
R22: 10k; R_0402_1005Metric
R23: 100k; R_0402_1005Metric
R24, R25: 1k; R_0402_1005Metric
SW1: NRST_KEY; SW_PUSH_6mm
SW2: USER_KEY; SW_PUSH_6mm
TP1: +3V3; TestPoint_Pad_D1.0mm
TP2: GND; TestPoint_Pad_D1.0mm
TP3: VCAP; TestPoint_Pad_D1.0mm
TP4: NRST; TestPoint_Pad_D1.0mm
TP5: BOOT0; TestPoint_Pad_D1.0mm
TP6: 3V3_SW; TestPoint_Pad_D1.0mm
U1: STM32H743ZIT6; LQFP-144_20x20mm_P0.5mm
U2: TPS54331DDAR; SOIC-8-1EP_3.9x4.9mm_P1.27mm_EP2.29x3mm
U3: USBLC6-2SC6; SOT-23-6
X1: 8MHz; Crystal_SMD_3215-2Pin_3.2x1.5mm
X2: 32.768kHz; Crystal_SMD_3215-2Pin_3.2x1.5mm

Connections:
3V3_SW: C24.1, C25.1, L1.2, R14.1, R15.1, TP6.1
5VIN: D6.2 (A), J6.1
BOOT: C23.1, U2.1 (BOOT)
BOOT0: J5.2, R23.1, TP5.1, U1.138 (BOOT0)
CC1: J3.A5 (CC1), R10.1
CC2: J3.B5 (CC2), R11.1
COMP: C27.1, R17.1, U2.6 (COMP)
COMP_M: C26.1, R17.2
FB: R15.2, R16.1, U2.5 (VSENSE)
LED_PWR: D8.2 (A), R24.2
LED_USER: D9.2 (A), R25.2
NRST: C54.1, J4.5, SW1.1, TP4.1, U1.25 (NRST)
OSC32_IN: C52.1, U1.8 (PC14), X2.1
OSC32_OUT: C53.1, U1.9 (PC15), X2.2
OSC_IN: C50.1, U1.23 (PH0), X1.1
OSC_OUT: C51.1, U1.24 (PH1), X1.2
PA0: J1.1, U1.34 (PA0)
PA1: J1.2, U1.35 (PA1)
PA2: J1.5, U1.36 (PA2)
PA3: J1.6, U1.37 (PA3)
PA4: J1.7, U1.40 (PA4)
PA5: J1.8, U1.41 (PA5)
PA6: J1.9, U1.42 (PA6)
PA7: J1.10, U1.43 (PA7)
PA8: J1.11, U1.100 (PA8)
PA9: J1.12, U1.101 (PA9)
PA10: J1.3, U1.102 (PA10)
PA13: J4.2, U1.105 (PA13)
PA14: J4.3, U1.109 (PA14)
PA15: J1.4, U1.110 (PA15)
PB0: D9.1 (K), J1.13, U1.46 (PB0)
PB1: J1.14, U1.47 (PB1)
PB2: J1.21, U1.48 (PB2)
PB3: J4.4, U1.133 (PB3)
PB4: J1.22, U1.134 (PB4)
PB5: J1.23, U1.135 (PB5)
PB6: J1.24, U1.136 (PB6)
PB7: J1.25, U1.137 (PB7)
PB8: J1.26, U1.139 (PB8)
PB9: J1.27, U1.140 (PB9)
PB10: J1.15, U1.69 (PB10)
PB11: J1.16, U1.70 (PB11)
PB12: J1.17, U1.73 (PB12)
PB13: J1.18, U1.74 (PB13)
PB14: J1.19, U1.75 (PB14)
PB15: J1.20, U1.76 (PB15)
PC0: J1.28, U1.26 (PC0)
PC1: J1.29, U1.27 (PC1)
PC2_C: J1.34, U1.28 (PC2_C)
PC3_C: J1.35, U1.29 (PC3_C)
PC4: J1.36, U1.44 (PC4)
PC5: J1.37, U1.45 (PC5)
PC6: J1.38, U1.96 (PC6)
PC7: J1.39, U1.97 (PC7)
PC8: J1.40, U1.98 (PC8)
PC9: J1.41, U1.99 (PC9)
PC10: J1.30, U1.111 (PC10)
PC11: J1.31, U1.112 (PC11)
PC12: J1.32, U1.113 (PC12)
PC13: C55.1, J1.33, SW2.1, U1.7 (PC13)
PD0: J1.42, U1.114 (PD0)
PD1: J1.43, U1.115 (PD1)
PD2: J1.50, U1.116 (PD2)
PD3: J1.51, U1.117 (PD3)
PD4: J1.52, U1.118 (PD4)
PD5: J1.53, U1.119 (PD5)
PD6: J2.1, U1.122 (PD6)
PD7: J2.2, U1.123 (PD7)
PD8: J2.3, U1.77 (PD8)
PD9: J2.4, U1.78 (PD9)
PD10: J1.44, U1.79 (PD10)
PD11: J1.45, U1.80 (PD11)
PD12: J1.46, U1.81 (PD12)
PD13: J1.47, U1.82 (PD13)
PD14: J1.48, U1.85 (PD14)
PD15: J1.49, U1.86 (PD15)
PDR_ON: R22.1, U1.143 (PDR_ON)
PE0: J2.5, U1.141 (PE0)
PE1: J2.6, U1.142 (PE1)
PE2: J2.13, U1.1 (PE2)
PE3: J2.14, U1.2 (PE3)
PE4: J2.15, U1.3 (PE4)
PE5: J2.16, U1.4 (PE5)
PE6: J2.17, U1.5 (PE6)
PE7: J2.18, U1.58 (PE7)
PE8: J2.19, U1.59 (PE8)
PE9: J2.20, U1.60 (PE9)
PE10: J2.7, U1.63 (PE10)
PE11: J2.8, U1.64 (PE11)
PE12: J2.9, U1.65 (PE12)
PE13: J2.10, U1.66 (PE13)
PE14: J2.11, U1.67 (PE14)
PE15: J2.12, U1.68 (PE15)
PF0: J2.21, U1.10 (PF0)
PF1: J2.22, U1.11 (PF1)
PF2: J2.29, U1.12 (PF2)
PF3: J2.30, U1.13 (PF3)
PF4: J2.31, U1.14 (PF4)
PF5: J2.32, U1.15 (PF5)
PF6: J2.33, U1.18 (PF6)
PF7: J2.34, U1.19 (PF7)
PF8: J2.35, U1.20 (PF8)
PF9: J2.36, U1.21 (PF9)
PF10: J2.23, U1.22 (PF10)
PF11: J2.24, U1.49 (PF11)
PF12: J2.25, U1.50 (PF12)
PF13: J2.26, U1.53 (PF13)
PF14: J2.27, U1.54 (PF14)
PF15: J2.28, U1.55 (PF15)
PG0: J2.37, U1.56 (PG0)
PG1: J2.38, U1.57 (PG1)
PG2: J2.45, U1.87 (PG2)
PG3: J2.46, U1.88 (PG3)
PG4: J2.47, U1.89 (PG4)
PG5: J2.48, U1.90 (PG5)
PG6: J2.49, U1.91 (PG6)
PG7: J2.50, U1.92 (PG7)
PG8: J2.51, U1.93 (PG8)
PG9: J2.52, U1.124 (PG9)
PG10: J2.39, U1.125 (PG10)
PG11: J2.40, U1.126 (PG11)
PG12: J2.41, U1.127 (PG12)
PG13: J2.42, U1.128 (PG13)
PG14: J2.43, U1.129 (PG14)
PG15: J2.44, U1.132 (PG15)
PH: C23.2, D7.1 (K), L1.1, U2.8 (PH)
SS: C28.1, U2.4 (SS)
USB_DM: U1.103 (PA11), U3.3 (I/O2)
USB_DM_P: J3.A7 (D-), J3.B7 (D-), U3.4 (I/O2)
USB_DP: U1.104 (PA12), U3.1 (I/O1)
USB_DP_P: J3.A6 (D+), J3.B6 (D+), U3.6 (I/O1)
VBAT: C48.1, R21.2, U1.6 (VBAT)
VBUS: F1.1, J3.A4 (VBUS), J3.A9 (VBUS), J3.B4 (VBUS), J3.B9 (VBUS), R12.1, U3.5 (VBUS)
VBUS_F: D5.2 (A), F1.2
VBUS_SENSE: R12.2, R13.1
VCAP: C40.1, C41.1, TP3.1, U1.71 (VCAP), U1.106 (VCAP)
VDDA: C42.1, C43.1, FB1.2, R20.1, U1.33 (VDDA)
VREF+: C44.1, C45.1, R20.2, U1.32 (VREF+)

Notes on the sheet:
电源输入与DCDC
USB(ESD保护)
MCU电源去耦(每VDD脚100nF就近+4.7uFx2, VCAPx2=2.2uF)
时钟(HSE 8MHz / LSE 32.768kHz)
复位 / BOOT0 / SWD
指示与人机
IO扩展(全部GPIO, PA13/14/PB3=SWD, PA11/12=USB 除外)

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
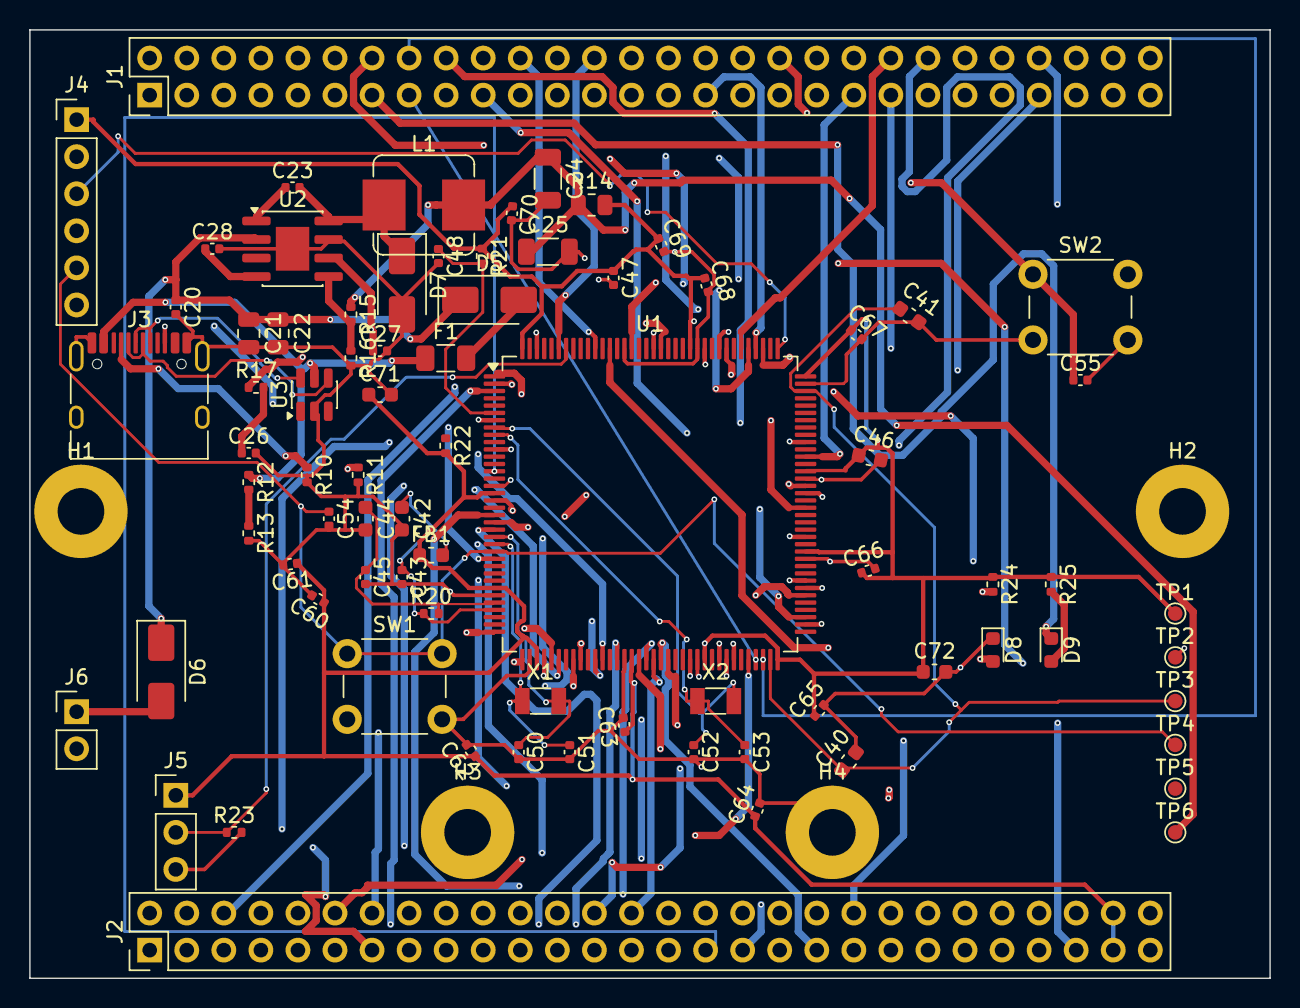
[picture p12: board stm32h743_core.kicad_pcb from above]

Board: 4 copper layers, 85.0 x 65.0 mm, 82 parts (0 on the bottom side), 141 nets.

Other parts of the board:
H1, H2, H3, H4: M3; MountingHole_3.2mm_M3_Pad

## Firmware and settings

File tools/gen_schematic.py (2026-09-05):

#!/usr/bin/env python3
"""STM32H743ZIT6 核心板原理图生成器(依据《STM32H743ZIT6_核心板设计规格书》§2-§7 与附录A)。

产物: kicad/stm32h743_core.kicad_sch
坐标: A2 图纸(594x420mm), 原点左上。
"""
import re
import sys
from pathlib import Path

sys.path.insert(0, str(Path(__file__).parent))
from sch_build import SchBuilder, LibCache
from project_config import KI, NET, SCH  # noqa: E402
from project_config import OUT

WS = Path(__file__).resolve().parents[1]

# ---------------------------------------------------------------- 封装常量
FP = {
    "R": "Resistor_SMD:R_0402_1005Metric",
    "C": "Capacitor_SMD:C_0402_1005Metric",
    "C0603": "Capacitor_SMD:C_0603_1608Metric",
    "C0805": "Capacitor_SMD:C_0805_2012Metric",
    "C1206": "Capacitor_SMD:C_1206_3216Metric",
    "L": "Inductor_SMD:L_Bourns_SRP7028A_7.3x6.6mm",
    "FB": "Inductor_SMD:L_0603_1608Metric",
    "D": "Diode_SMD:D_SMA",
    "F": "Fuse:Fuse_1206_3216Metric",
    "LED": "LED_SMD:LED_0603_1608Metric",
    "SW": "Button_Switch_THT:SW_PUSH_6mm",
    "USBC": "Connector_USB:USB_C_Receptacle_HRO_TYPE-C-31-M-12",
    "ESD": "Package_TO_SOT_SMD:SOT-23-6",
    "DCDC": "Package_SO:SOIC-8-1EP_3.9x4.9mm_P1.27mm_EP2.29x3mm",
    "MCU": "Package_QFP:LQFP-144_20x20mm_P0.5mm",
    "H228": "Connector_PinHeader_2.54mm:PinHeader_2x28_P2.54mm_Vertical",
    "H106": "Connector_PinHeader_2.54mm:PinHeader_1x06_P2.54mm_Vertical",
    "H103": "Connector_PinHeader_2.54mm:PinHeader_1x03_P2.54mm_Vertical",
    "H102": "Connector_PinHeader_2.54mm:PinHeader_1x02_P2.54mm_Vertical",
}

# ---------------------------------------------------------------- TPS54331 自建符号
TPS54331_BLOCK = '''(symbol "TPS54331DDA"
	(pin_names (offset 1.016))
	(in_bom yes) (on_board yes)
	(property "Reference" "U" (at 0 13.97 0) (effects (font (size 1.27 1.27))))
	(property "Value" "TPS54331DDA" (at 0 -13.97 0) (effects (font (size 1.27 1.27))))
	(property "Footprint" "" (at 0 0 0) (effects (font (size 1.27 1.27)) (hide yes)))
	(property "Datasheet" "" (at 0 0 0) (effects (font (size 1.27 1.27)) (hide yes)))
	(symbol "TPS54331DDA_0_1"
		(rectangle (start -7.62 11.43) (end 7.62 -11.43)
			(stroke (width 0.254) (type default)) (fill (type background)))
	)
	(symbol "TPS54331DDA_1_1"
		(pin output line (at -12.7 7.62 0) (length 5.08)
			(name "BOOT" (effects (font (size 1.27 1.27)))) (number "1" (effects (font (size 1.27 1.27)))))
		(pin power_in line (at -12.7 2.54 0) (length 5.08)
			(name "VIN" (effects (font (size 1.27 1.27)))) (number "2" (effects (font (size 1.27 1.27)))))
		(pin input line (at -12.7 -2.54 0) (length 5.08)
			(name "EN" (effects (font (size 1.27 1.27)))) (number "3" (effects (font (size 1.27 1.27)))))
		(pin input line (at -12.7 -7.62 0) (length 5.08)
			(name "SS" (effects (font (size 1.27 1.27)))) (number "4" (effects (font (size 1.27 1.27)))))
		(pin input line (at 12.7 7.62 180) (length 5.08)
			(name "VSENSE" (effects (font (size 1.27 1.27)))) (number "5" (effects (font (size 1.27 1.27)))))
		(pin output line (at 12.7 2.54 180) (length 5.08)
			(name "COMP" (effects (font (size 1.27 1.27)))) (number "6" (effects (font (size 1.27 1.27)))))
		(pin power_in line (at 12.7 -2.54 180) (length 5.08)
			(name "GND" (effects (font (size 1.27 1.27)))) (number "7" (effects (font (size 1.27 1.27)))))
		(pin output line (at 12.7 -7.62 180) (length 5.08)
			(name "PH" (effects (font (size 1.27 1.27)))) (number "8" (effects (font (size 1.27 1.27)))))
		(pin power_in line (at 0 -16.51 90) (length 5.08)
			(name "EP" (effects (font (size 1.27 1.27)))) (number "9" (effects (font (size 1.27 1.27)))))
	)
)'''

# ---------------------------------------------------------------- MCU 引脚→网络规则(附录A)
POWER_NETS = ("GND", "+3V3", "+5V")

def mcu_net(num: int, name: str) -> str:
    if name == "VCAP":
        return "VCAP"  # AN4938 Rev7 §2.2 + MB1364E sheet 4: tie both pins, local 2.2uF each.
    if name in ("VDD", "VDD33_USB"):
        return "+3V3"
    if name in ("VSS", "VSSA"):
        return "GND"
    return {"VDDA": "VDDA", "VREF+": "VREF+", "VBAT": "VBAT", "PDR_ON": "PDR_ON",
            "NRST": "NRST", "BOOT0": "BOOT0", "PH0": "OSC_IN", "PH1": "OSC_OUT",
            "PC14": "OSC32_IN", "PC15": "OSC32_OUT",
            "PA11": "USB_DM", "PA12": "USB_DP"}.get(name, name)

SWD_GPIO = {"PA13", "PA14", "PB3"}          # 专用 SWD, 不上排针
USB_GPIO = {"PA11", "PA12"}                  # 专用 USB
OSC_GPIO = {"PC14", "PC15", "PH0", "PH1"}    # 晶振占用


def conn(b, inst, pin, net, len_lbl=3.81, len_pwr=5.08):
    if net in POWER_NETS:
        b.pin_power(inst, pin, net, len_pwr)
    else:
        b.pin_label(inst, pin, net, len_lbl)


def two_pin(b, lib_id, ref, val, fp, x, y, net1, net2, angle=0, dnp=False):
    inst = b.place(lib_id, ref, val, fp, x, y, angle=angle, dnp=dnp)
    conn(b, inst, "1", net1)
    conn(b, inst, "2", net2)
    return inst


def rc(b, ref, val, fp, x, y, top, bot):
    """竖直两端器件(R/C 默认 pin1 上 pin2 下)。"""
    return two_pin(b, {"R": "Device:R", "C": "Device:C"}[ref[0]], ref, val, fp, x, y, top, bot)


def build():
    b = SchBuilder("STM32H743ZIT6 核心板(最小系统)", paper="A2", project="stm32h743_core")
    mcu_lib = LibCache.load("MCU_ST_STM32H7:STM32H743ZITx")

    # ================= MCU =================
    u1 = b.place("MCU_ST_STM32H7:STM32H743ZITx", "U1", "STM32H743ZIT6", FP["MCU"], 270, 140)
    mcu_pins = {int(p.number): p for p in mcu_lib.pins}  # 按引脚号去重
    drawn = {}  # 世界坐标 -> 网络; 同坐标只画一次引线(符号内同名电源脚叠画)
    rail_pts = []
    for num in sorted(mcu_pins):
        net = mcu_net(num, mcu_pins[num].name)
        pos = tuple(round(v, 2) for v in u1.pin_pos(str(num)))
        if pos in drawn:
            assert drawn[pos] == net, f"坐标 {pos} 上不同网络叠加: {drawn[pos]} vs {net}"
            continue
        drawn[pos] = net
        if net == "+3V3" and u1.pin_dir(str(num)) == (0, -1):
            rail_pts.append(pos)      # 顶部 VDD 群走汇流排
            continue
        conn(b, u1, str(num), net)
    b.rail(rail_pts, "+3V3")

    gpio = sorted({p.name for num, p in mcu_pins.items()
                   if re.fullmatch(r"P[A-K]\d+(_C)?", p.name)
                   and p.name not in SWD_GPIO | USB_GPIO | OSC_GPIO
                   and mcu_net(num, p.name) == p.name},
                  key=lambda n: (n[1], n[2:].rstrip("_C"), len(n)))
    assert len(gpio) == 105, f"GPIO 数量异常: {len(gpio)}"

    # ================= 电源输入与 DCDC (左上) =================
    b.note("电源输入与DCDC", 25, 20, 2)
    # USB-C 与 5VIN 输入合路
    j3 = b.place("Connector:USB_C_Receptacle_USB2.0_16P", "J3", "USB_C", FP["USBC"], 35, 100)
    drawn = set()  # 该符号多个电源脚共享同一坐标, 每个坐标只画一次引线
    for p in j3.lib.pins:
        nm = p.name.split("/")[-1]
        net = {"GND": "GND", "VBUS": "VBUS", "CC1": "CC1", "CC2": "CC2",
               "D+": "USB_DP_P", "D-": "USB_DM_P", "SHIELD": "GND"}.get(nm)
        if not net:
            continue
        pos = tuple(round(v, 2) for v in j3.pin_pos(p.number))
        if pos in drawn:
            continue
        drawn.add(pos)
        conn(b, j3, p.number, net)
    two_pin(b, "Device:R", "R10", "5.1k", FP["R"], 75, 95, "CC1", "GND")
    two_pin(b, "Device:R", "R11", "5.1k", FP["R"], 85, 95, "CC2", "GND")
    # USB 后级: 保险丝 → 二极管合路(电流方向: 输入→+5V, 故 K 极朝 +5V)
    two_pin(b, "Device:Polyfuse", "F1", "500mA", FP["F"], 100, 70, "VBUS", "VBUS_F")
    two_pin(b, "Device:D_Schottky", "D5", "SS34", FP["D"], 120, 70, "+5V", "VBUS_F")
    j6 = b.place("Connector_Generic:Conn_01x02", "J6", "5VIN", FP["H102"], 25, 60)
    conn(b, j6, "1", "5VIN")
    conn(b, j6, "2", "GND")
    two_pin(b, "Device:D_Schottky", "D6", "SS34", FP["D"], 120, 60, "+5V", "5VIN")
    # VBUS 检测分压(DNP, 默认不装)
    two_pin(b, "Device:R", "R12", "68k", FP["R"], 150, 95, "VBUS", "VBUS_SENSE", dnp=True)
    two_pin(b, "Device:R", "R13", "100k", FP["R"], 160, 95, "VBUS_SENSE", "GND", dnp=True)
    # DCDC 主芯片
    u2 = b.place("hagent:TPS54331DDA", "U2", "TPS54331DDAR", FP["DCDC"], 55, 55,
                 custom_block=TPS54331_BLOCK, val_off=(0, 18.5))
    for pin, net in {"1": "BOOT", "2": "+5V", "4": "SS", "5": "FB", "6": "COMP", "7": "GND", "8": "PH", "9": "GND"}.items():
        conn(b, u2, pin, net)
    rc(b, "C28", "10n", FP["C"], 30, 42, "SS", "GND")  # TPS54331 SS 慢启动电容(TI §7.3.5: 内部无软启动, CSS<=27nF)
    two_pin(b, "Device:C", "C20", "100n", FP["C"], 48, 25, "+5V", "GND")          # 输入
    two_pin(b, "Device:C", "C21", "10uF", FP["C0805"], 35, 45, "+5V", "GND")
    two_pin(b, "Device:C", "C22", "10uF", FP["C0805"], 35, 60, "+5V", "GND")
    two_pin(b, "Device:C", "C23", "100n", FP["C"], 95, 40, "BOOT", "PH")          # 自举
    two_pin(b, "Device:D_Schottky", "D7", "SS34", FP["D"], 95, 90, "PH", "GND")   # 续流(K上A下)
    two_pin(b, "Device:L", "L1", "6.8uH/4A", FP["L"], 120, 110, "PH", "3V3_SW")
    two_pin(b, "Device:R", "R14", "0R", "Resistor_SMD:R_0805_2012Metric", 145, 110, "3V3_SW", "+3V3")
    two_pin(b, "Device:C", "C24", "47uF", FP["C1206"], 160, 120, "3V3_SW", "GND")
    two_pin(b, "Device:C", "C25", "47uF", FP["C1206"], 168, 120, "3V3_SW", "GND")
    two_pin(b, "Device:R", "R15", "10.2k", FP["R"], 30, 150, "3V3_SW", "FB")  # Sense BEFORE removable current link.
    two_pin(b, "Device:R", "R16", "3.24k", FP["R"], 42, 162, "FB", "GND")
    two_pin(b, "Device:R", "R17", "29.4k", FP["R"], 95, 125, "COMP", "COMP_M")    # II 型补偿
    two_pin(b, "Device:C", "C26", "1nF", FP["C"], 105, 138, "COMP_M", "GND")
    two_pin(b, "Device:C", "C27", "47pF", FP["C"], 85, 138, "COMP", "GND")

    # ================= USB ESD (右上) =================
    b.note("USB(ESD保护)", 340, 20, 2)
    u3 = b.place("Power_Protection:USBLC6-2SC6", "U3", "USBLC6-2SC6", FP["ESD"], 400, 55)
    for pin, net in {"1": "USB_DP", "3": "USB_DM", "4": "USB_DM_P", "5": "VBUS",
                     "6": "USB_DP_P", "2": "GND"}.items():
        conn(b, u3, pin, net)

    # ================= 去耦与特殊电源 (左中) =================
    b.note("MCU电源去耦(每VDD脚100nF就近+4.7uFx2, VCAPx2=2.2uF)", 25, 205, 2)
    col_x = [40, 70, 100, 130]
    row_y = [225, 240, 255, 270, 285, 300, 315]
    decap = [*[("100nF", FP["C"])] * 11, ("4.7uF", FP["C0603"]), ("4.7uF", FP["C0603"])]
    i = 0
    for val, fp in decap:
        rc(b, f"C{60 + i}", val, fp, col_x[i % 4], row_y[i // 4], "+3V3", "GND")
        i += 1
    rc(b, "C40", "2.2uF", FP["C0603"], 150, 320, "VCAP", "GND")
    rc(b, "C41", "2.2uF", FP["C0603"], 165, 320, "VCAP", "GND")
    rc(b, "C42", "1uF", FP["C0603"], 150, 340, "VDDA", "GND")
    rc(b, "C43", "100nF", FP["C"], 165, 340, "VDDA", "GND")
    rc(b, "C44", "1uF", FP["C0603"], 150, 360, "VREF+", "GND")
    rc(b, "C45", "100n", FP["C"], 165, 360, "VREF+", "GND")
    rc(b, "C46", "1uF", FP["C0603"], 180, 320, "+3V3", "GND")      # VDD33_USB
    rc(b, "C47", "100n", FP["C"], 180, 340, "+3V3", "GND")
    two_pin(b, "Device:FerriteBead", "FB1", "600R@100MHz", FP["FB"], 180, 360, "+3V3", "VDDA")
    two_pin(b, "Device:R", "R20", "0R", FP["R"], 180, 378, "VDDA", "VREF+")
    two_pin(b, "Device:R", "R21", "0R", FP["R"], 40, 370, "+3V3", "VBAT")
    rc(b, "C48", "100nF", FP["C"], 90, 370, "VBAT", "GND")
    two_pin(b, "Device:R", "R22", "10k", FP["R"], 60, 370, "PDR_ON", "+3V3")

    # ================= 时钟 (下方左) =================
    b.note("时钟(HSE 8MHz / LSE 32.768kHz)", 25, 390, 2)
    two_pin(b, "Device:Crystal", "X1", "8MHz", "Crystal:Crystal_SMD_3215-2Pin_3.2x1.5mm", 40, 330, "OSC_IN", "OSC_OUT")
    two_pin(b, "Device:C", "C50", "18pF", FP["C"], 55, 318, "OSC_IN", "GND")
    two_pin(b, "Device:C", "C51", "18pF", FP["C"], 55, 342, "OSC_OUT", "GND")
    two_pin(b, "Device:Crystal", "X2", "32.768kHz", "Crystal:Crystal_SMD_3215-2Pin_3.2x1.5mm", 110, 330, "OSC32_IN", "OSC32_OUT")
    two_pin(b, "Device:C", "C52", "18pF", FP["C"], 125, 318, "OSC32_IN", "GND")
    two_pin(b, "Device:C", "C53", "18pF", FP["C"], 125, 342, "OSC32_OUT", "GND")

    # ================= 复位/启动/调试 (下方中) =================
    b.note("复位 / BOOT0 / SWD", 200, 390, 2)
    two_pin(b, "Switch:SW_Push", "SW1", "NRST_KEY", FP["SW"], 200, 330, "NRST", "GND")
    two_pin(b, "Device:C", "C54", "100nF", FP["C"], 218, 330, "NRST", "GND")
    two_pin(b, "Device:R", "R23", "100k", FP["R"], 236, 330, "BOOT0", "GND")
    j5 = b.place("Connector_Generic:Conn_01x03", "J5", "BOOT", FP["H103"], 258, 330)
    for pin, net in {"1": "+3V3", "2": "BOOT0", "3": "GND"}.items():
        conn(b, j5, pin, net)
    j4 = b.place("Connector_Generic:Conn_01x06", "J4", "SWD", FP["H106"], 285, 330)
    for pin, net in {"1": "+3V3", "2": "PA13", "3": "PA14", "4": "PB3", "5": "NRST", "6": "GND"}.items():
        conn(b, j4, pin, net)

    # ================= 指示与人机 (右侧下) =================
    b.note("指示与人机", 350, 200, 2)
    two_pin(b, "Device:R", "R24", "1k", FP["R"], 360, 220, "+3V3", "LED_PWR")
    two_pin(b, "Device:LED", "D8", "PWR_GREEN", FP["LED"], 360, 240, "GND", "LED_PWR")
    two_pin(b, "Device:R", "R25", "1k", FP["R"], 390, 220, "+3V3", "LED_USER")
    two_pin(b, "Device:LED", "D9", "USER_BLUE", FP["LED"], 390, 240, "PB0", "LED_USER")
    two_pin(b, "Switch:SW_Push", "SW2", "USER_KEY", FP["SW"], 420, 220, "PC13", "GND")
    two_pin(b, "Device:C", "C55", "100nF", FP["C"], 440, 220, "PC13", "GND")
    # 测试点
    for k, (ref, net) in enumerate([("TP1", "+3V3"), ("TP2", "GND"), ("TP3", "VCAP"),
                                    ("TP4", "NRST"), ("TP5", "BOOT0"), ("TP6", "3V3_SW")]):
        tp = b.place("Connector:TestPoint", ref, net, "TestPoint:TestPoint_Pad_D1.0mm", 460, 215 + k * 12)
        conn(b, tp, "1", net)

    # ================= IO 排针 (最右, 2x28 x2) =================
    b.note("IO扩展(全部GPIO, PA13/14/PB3=SWD, PA11/12=USB 除外)", 480, 20, 2)
    def header(ref, x, y, nets):
        h = b.place("Connector_Generic:Conn_02x28_Odd_Even", ref, "GPIO", FP["H228"], x, y)
        for pin, net in nets.items():
            conn(b, h, str(pin), net, len_lbl=3.81, len_pwr=3.81)
        return h
    j1_nets = {i + 1: gpio[i] for i in range(53)}
    j1_nets.update({54: "+3V3", 55: "GND", 56: "GND"})
    j2_nets = {i + 1: gpio[53 + i] for i in range(52)}
    j2_nets.update({53: "+3V3", 54: "+3V3", 55: "GND", 56: "GND"})
    header("J1", 520, 60, j1_nets)
    header("J2", 520, 165, j2_nets)

    return b


def export_netlist():
    """artifact lineage: 原理图一变就强制重导网表, 不允许复用旧 .net。"""
    import subprocess
    from project_config import KI, NET, SCH
    if NET.exists():
        NET.unlink()  # 先删旧网表, 防止导出失败时留下陈旧产物
    r = subprocess.run([str(KI / "kicad-cli.exe"), "sch", "export", "netlist",
                        "--format", "kicadsexpr", "--output", str(NET), str(SCH)],
                       capture_output=True, text=True)
    if r.returncode != 0 or not NET.exists():
        print(r.stdout, r.stderr)
        raise SystemExit("网表导出失败")
    print(f"网表已重导: {NET}")


if __name__ == "__main__":
    b = build()
    # 自检: 引线段不得共线重叠(会意外并网)
    def seg(w):
        (x1, y1), (x2, y2) = w
        return (x1, y1, x2, y2)
    wires = sorted(b.wires, key=lambda w: (w[0][0], w[0][1], w[1][0], w[1][1]))
    bad = []
    for i in range(len(wires)):
        x1, y1, x2, y2 = seg(wires[i])
        for j in range(i + 1, len(wires)):
            a1, b1, a2, b2 = seg(wires[j])
            if a1 > x2 or (a1 == x1 and b1 > y2):
                break
            # 共线且区间重叠
            if abs(x1 - x2) < 1e-6 and abs(a1 - a2) < 1e-6 and abs(x1 - a1) < 1e-6:
                lo1, hi1 = sorted((y1, y2)); lo2, hi2 = sorted((b1, b2))
                if max(lo1, lo2) < min(hi1, hi2):
                    bad.append((wires[i], wires[j]))
            elif abs(y1 - y2) < 1e-6 and abs(b1 - b2) < 1e-6 and abs(y1 - b1) < 1e-6:
                lo1, hi1 = sorted((x1, x2)); lo2, hi2 = sorted((a1, a2))
                if max(lo1, lo2) < min(hi1, hi2):
                    bad.append((wires[i], wires[j]))
    if bad:
        print(f"!! {len(bad)} 处引线重叠:")
        for w1, w2 in bad[:10]:
            print("   ", w1, "<->", w2)
        sys.exit(1)
    out = OUT / "stm32h743_core.kicad_sch"
    out.parent.mkdir(parents=True, exist_ok=True)
    b.write(out)
    print(f"已生成 {out}")
    export_netlist()
    print(f"元件 {len(b.symbols)} 个, 走线 {len(b.wires)} 段, 标签 {len(b.labels)} 个, 电源口 {len(b.powers)} 个")

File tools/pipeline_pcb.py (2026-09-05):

#!/usr/bin/env python3
"""PCB 流水线编排(系统 python): DSN 分类 -> Freerouting -> SES 回写 -> DRC -> Release Gate -> 制造文件。

用法: python tools/pipeline_pcb.py [--max-passes 25]
"""
import json
import subprocess
import sys
from pathlib import Path

WS = Path(__file__).resolve().parents[1]
FR_DIR = WS / "tools" / "freerouting"
JAVA = FR_DIR / "jdk-25.0.4.1+1-jre" / "bin" / "java.exe"
JAR = FR_DIR / "freerouting.jar"

sys.path.insert(0, str(WS / "tools"))
from project_config import (  # noqa: E402
    CLEARANCE,
    DSN,
    GND_TRACE_WIDTH,
    IN2_ALLOWED_SIGNAL_NETS,
    KI,
    PCB,
    POWER_WIDTH,
    SES,
    SIGNAL_LAYERS,
    SIGNAL_WIDTH,
)

# Current experiment-B routing classes.
# In1 remains GND-only. In2 may carry +3V3 plus explicit ordinary GPIO names.
LAYER_PLAN = [
    ("GND", ["GND"], GND_TRACE_WIDTH, ["In1.Cu", *SIGNAL_LAYERS]),
    ("P3V3", ["+3V3"], POWER_WIDTH, ["In2.Cu", *SIGNAL_LAYERS]),
    ("POW5", ["+5V", "VBUS", "VBUS_F", "5VIN", "PH", "3V3_SW", "BOOT"], POWER_WIDTH, list(SIGNAL_LAYERS)),
    ("SIG2", None, SIGNAL_WIDTH, ["F.Cu", "In2.Cu", "B.Cu"]),
    ("Default", None, SIGNAL_WIDTH, list(SIGNAL_LAYERS)),
]
POWER_NETS = LAYER_PLAN[1][1] + LAYER_PLAN[2][1]
NL = chr(10)


def edit_dsn_power_class():
    """按 LAYER_PLAN 把网络分入带 use_layer 约束的类。"""
    text = DSN.read_text(encoding="utf-8")
    # DSN 每次应由 gen_pcb 新导出；若发现已分类，拒绝静默复用旧实验配置。
    if "(class GND " in text or "(class SIG2 " in text:
        raise SystemExit("!! DSN 已包含自定义层类；请从当前 PCB 重新导出 DSN 后再执行 dsn 步骤")
    i = text.find("(class kicad_default")
    assert i >= 0, "DSN 无 kicad_default 类"
    depth, j = 0, i
    while j < len(text):
        if text[j] == "(":
            depth += 1
        elif text[j] == ")":
            depth -= 1
            if depth == 0:
                break
        j += 1
    block = text[i:j + 1]
    ck = block.find("(circuit")
    head_tokens = block[:ck].split()[1:]
    tail = block[ck:]
    v0 = tail.find('"') + 1
    v1 = tail.find('"', v0)
    use_via = tail[v0:v1]

    buckets = {plan[0]: [] for plan in LAYER_PLAN}
    for tok in head_tokens:
        for name, members, _, _ in LAYER_PLAN:
            if members and tok in members:
                buckets[name].append(tok)
                break
        else:
            buckets["SIG2" if tok in IN2_ALLOWED_SIGNAL_NETS else "Default"].append(tok)

    new_blocks = ""
    for name, members, width, layers in LAYER_PLAN:
        nets = buckets[name]
        if not nets:
            continue
        w_units = int(width * 1000)
        clearance_units = int(CLEARANCE * 1000)
        circ = (
            "      (circuit" + NL
            + "        (use_layer " + " ".join(layers) + ")" + NL
            + "        (use_via \"" + use_via + "\")" + NL
            + "      )"
        )
        rule = (
            "      (rule" + NL
            + "        (width " + str(w_units) + ")" + NL
            + "        (clearance " + str(clearance_units) + ")" + NL
            + "      )"
        )
        new_blocks += (
            "    (class " + name + " " + " ".join(nets) + NL
            + circ + NL + rule + NL + "    )" + NL
        )
    text = text[:i] + new_blocks.rstrip() + NL + text[j + 1:]
    DSN.write_text(text, encoding="utf-8")
    counts = ", ".join(pp[0] + "=" + str(len(buckets[pp[0]])) for pp in LAYER_PLAN)
    print("DSN 层类已写入: " + counts)


def run_freerouting(max_passes: int):
    cmd = [str(JAVA), "-jar", str(JAR), "-de", str(DSN), "-do", str(SES),
           "-mp", str(max_passes), "-mt", "1", "-l", "en"]
    print("Freerouting:", " ".join(cmd[1:]), flush=True)
    with open(WS / "kicad" / "freerouting.log", "w", encoding="utf-8") as logf:
        p = subprocess.Popen(cmd, stdout=logf, stderr=subprocess.STDOUT, cwd=str(FR_DIR))
        try:
            rc = p.wait(timeout=5400)
        except subprocess.TimeoutExpired:
            p.kill()
            print("!! Freerouting 超时(5400s)被终止")
            raise SystemExit(1)
    log = (WS / "kicad" / "freerouting.log").read_text(encoding="utf-8", errors="replace")
    if rc != 0:
        print(f"!! Freerouting 退出码 {rc}\n{log[-1500:]}")
        raise SystemExit(1)
    done = "100%" in log or "route completed" in log.lower()
    print(f"Freerouting 完成(exit {rc}, 100%布通标记={'有' if done else '无'})")
    for line in log.splitlines():
        if "Auto-routing stage completed" in line or "Fanout stage completed" in line:
            print("  ", line.split("INFO")[-1].strip()[:200])
    return SES.exists()


def run(cmd, **kw):
    r = subprocess.run([str(c) for c in cmd], capture_output=True, text=True, **kw)
    if r.returncode != 0:
        print("!! 命令失败:", " ".join(str(c) for c in cmd))
        print((r.stdout or "")[-800:], (r.stderr or "")[-800:])
        raise SystemExit(r.returncode or 1)
    return r


def drc():
    run([KI / "kicad-cli.exe", "pcb", "drc", "--format", "json",
         "--schematic-parity", "--output", WS / "kicad" / "drc.json", PCB])
    rep = json.loads((WS / "kicad" / "drc.json").read_text(encoding="utf-8"))
    viol = rep.get("violations", [])
    unc = rep.get("unconnected_items", [])
    errs_v = [v for v in viol if v.get("severity") == "error"]
    errs_u = [v for v in unc if v.get("severity") == "error"]
    print(f"DRC: 违规 {len(viol)} (error {len(errs_v)}), 未连通 {len(unc)} (error {len(errs_u)})")
    for v in (errs_v + errs_u)[:15]:
        items = v.get("items", [])
        pos = items[0].get("pos") if items else {}
        print(f"   [{v.get('type')}] {v.get('description', '')[:90]} @ {pos}")
    return len(errs_v) + len(errs_u)


def release_gate():
    run([sys.executable, WS / "tools" / "release_gate.py"], cwd=str(WS))


def fab_outputs():
    # Fail closed: manufacturing export is not allowed without the full gate.
    release_gate()
    gdir = WS / "kicad" / "gerbers"
    gdir.mkdir(exist_ok=True)
    run([KI / "kicad-cli.exe", "pcb", "export", "gerbers", "--output", gdir, PCB])
    run([KI / "kicad-cli.exe", "pcb", "export", "drill", "--output", gdir,
         "--format", "excellon", "--excellon-units", "mm", PCB])
    run([KI / "kicad-cli.exe", "pcb", "export", "pos", "--format", "csv", "--units", "mm",
         "--output", WS / "kicad" / "pos.csv", PCB])
    run([KI / "kicad-cli.exe", "sch", "export", "bom",
         "--output", WS / "kicad" / "bom.csv",
         "--fields", "Reference,Value,Footprint,${QUANTITY}",
         "--group-by", "Value,Footprint",
         WS / "kicad" / "stm32h743_core.kicad_sch"])
    print(f"制造文件: {gdir} (Gerber+钻孔), kicad/pos.csv, kicad/bom.csv")
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

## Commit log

2026-09-05 STM32H743ZIT6 核心板：规格驱动的全自动 EDA 流水线（原理图+PCB+制造文件）
    - 规格书驱动的原理图/PCB 全脚本生成（KiCad 10 + pcbnew API + Freerouting）
    - 阶段0 引脚真源核验：KiCad 符号库 ↔ DS12110 数据手册交叉比对
    - 网表门禁 + 布局包围盒碰撞断言 + DRC 闭环（0 error / 0 未连通）
    - 附完整方法论与踩坑实录（doc/方法论与流程记录.md）
    [bom.csv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]
2026-09-05 feat: add semantic schematic parity gate
2026-09-05 feat: 执行层策略——SS 电容 C28、DSN 层类约束、飞线预布线改 B.Cu
    - 规格/生成器: TPS54331 SS 外接 C28 10nF(TI §7.3.5 内部无软启动)
    - 网表门禁: VCAP 单网、3V3_SW 迁移、SS 规则、LED 极性同步
    - gen_pcb: 飞线预布线全部改 B.Cu(层策略), 过孔入盘 0.4/0.2, R14 挪位+C48
    - pipeline: DSN 按层策略分四类(GND/P3V3/POW5/Default)带 use_layer 约束
    - 状态: 层策略门禁首次通过; DRC 25 未连通+7 error, 收敛方案待决策
    [stm32h743_core.dsn, stm32h743_core.kicad_pcb, stm32h743_core.kicad_sch]
2026-09-05 docs: 方法论新增「待决策事项与当前 WIP」——层策略三方案与收尾清单
2026-09-05 chore: align shared fabrication rules with current spec
2026-09-05 fix: make TPS54331 SS capacitor a hard netlist requirement
    [check_netlist.py]
2026-09-05 fix: fail parity gate on missing PCB footprints
    [check_schematic_parity.py]
2026-09-05 feat: add fail-closed release gate for EDA artifacts
    [release_gate.py]
2026-09-05 wip: 层策略实验B全链路——0 error未能达成, 如实落盘WIP状态与决策点
    - 实验 A/B/B2 数据: 等效配置下未连通 18/25/44/54, Freerouting 存在运行间方差
    - build_status.json + README 状态改 WIP/NOT FAB-READY (release_gate fail-closed)
    - 已知余量: PB10/PB11 相邻入盘过孔 0.1mm、若干 0.13-0.149 近 miss 间距、未连通信号网
    - 决策点: 双GND平面 / 严格策略硬磨 / 维持折中 —— 见方法论 §5.3
    [stm32h743_core.dsn, stm32h743_core.kicad_pcb]
2026-09-05 fix: make In2 routing policy explicit and fail-closed
    [project_config.py]
2026-09-05 fix: enforce explicit In2 signal whitelist
    [check_layer_policy.py]
2026-09-05 fix: use signal width for In2 experiment and gate fab export
    [pipeline_pcb.py]
2026-09-05 fix: extend release lineage checks to generator sources
    [release_gate.py]
2026-09-05 docs: align README with current WIP and gated fab export
2026-09-05 docs+data: 层策略 A/B/B2 实验实录与结构性结论——四层 F/B-only 自动布线不收敛
    [stm32h743_core.dsn, stm32h743_core.kicad_pcb]
2026-09-05 data+fix: 实验B三次独立运行批次数据——未连通稳定55条(固定拓扑瓶颈), U2.4负测试修复
    - run_batch.py: KI 定义/断点续跑/DRC调用修正
    - 3 runs same fresh DSN: unrouted 8/8/8, DRC unconnected 55/55/55 (固定拓扑瓶颈)
    - 层策略门禁 PASS (In1 纯GND, In2 +3V3+白名单)
    - 负测试 5/5: SS改名/U2.4删除/PD13走In1/缺封装/lineage 全部拦截
    - build_status.json + 方法论 5.5 实验表更新
    [board_run1.kicad_pcb, board_run2.kicad_pcb, board_run3.kicad_pcb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]
